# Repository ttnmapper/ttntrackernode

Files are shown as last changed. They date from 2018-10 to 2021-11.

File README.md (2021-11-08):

# TTN Tracker

The TTN Tracker is a [Things Network](https://www.thethingsnetwork.org/) node with a gps, used to map out coverage on [TTN Mapper](https://ttnmapper.org/). The device is aimed at end users, but can also be reprogrammed by more advanced users.

Thisrepository contains the schematics used to create the device as well as any additional files and the firmware that was loaded on the device.

### Schematics
The schematics were created using [KiCad 4.0.7](http://kicad.org/)

# Datasheets

These are links to the datasheets of important components used in the design.

 * [ATMEGA32U4](http://ww1.microchip.com/downloads/en/DeviceDoc/Atmel-7766-8-bit-AVR-ATmega16U4-32U4_Datasheet.pdf)  - Main Microcontroller
 * [RN2483](http://ww1.microchip.com/downloads/en/DeviceDoc/50002346C.pdf) - LoRa Module
 * [UBlox Cam M8Q](https://www.u-blox.com/sites/default/files/CAM-M8-FW3_DataSheet_%28UBX-15031574%29.pdf) - GPS
 	[Alternate datasheet](https://www.u-blox.com/sites/default/files/CAM-M8-FW3_HardwareIntegrationManual_%28UBX-15030063%29.pdf)
 * [MMA8452Q](https://www.nxp.com/docs/en/data-sheet/MMA8452Q.pdf) - Accelerometer
 * [MCP73831](http://ww1.microchip.com/downloads/en/DeviceDoc/20001984g.pdf) - LiPo Battery Charge management
 * [TLV71333PDBV](http://www.ti.com/lit/ds/symlink/tlv713p.pdf) - 3.3v Regulator

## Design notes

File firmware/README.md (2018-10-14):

# Firmware

All firmware was written in the Ardiuno IDE.

## Required Libraries

RN2xx3 Arduino Library from here:
https://github.com/jpmeijers/RN2483-Arduino-Library/

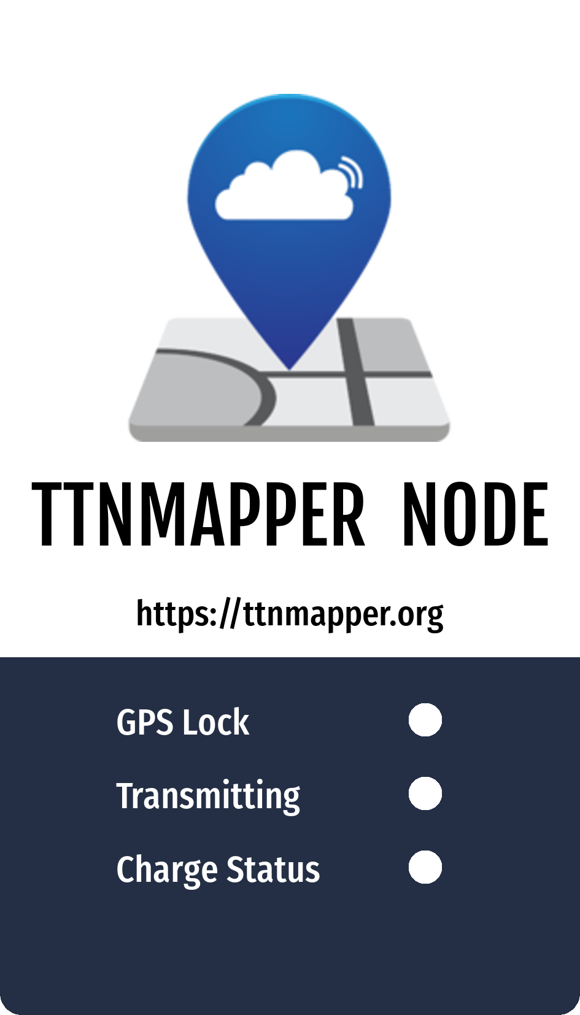
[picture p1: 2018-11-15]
enclosure/sticker design/tracker_sticker.png

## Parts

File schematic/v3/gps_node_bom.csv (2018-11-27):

Source: | C:\Users\Kolijn\Temp\ttntrackernode\schematic\v3\gps_node.sch
Date: | 2018/11/27 15:08:40
Tool: | Eeschema (5.0.1)-3
Generator: | C:\Program Files\KiCad\bin\scripting\plugins/bom_csv_grouped_by_value_with_fp.py
Component Count: | 86
Ref | Qnty | Value | Cmp name | Footprint | Description | Vendor |  | Digikey |  | RS
C4, C22, C29, C28, C20, C17, C7, C8, C9, C10, C11, C12, C23, C24, C13, C25, C27, | 17 | 100nF | C-Device | Capacitor_SMD:C_0805_2012Metric |  |  |  | 311-1361-1-ND | 0.16
C14, C15, | 2 | 22pF | C | Capacitor_SMD:C_0805_2012Metric | Unpolarized capacitor |  |  | 399-8036-1-ND | 0.14
C16, | 1 | 1uF | C-Device | Capacitor_SMD:C_0805_2012Metric |  |  |  | 399-1284-1-ND | 0.17
C18, C21, C30, C2, C6, C5, C3, C26, | 8 | 4.7uF | C-Device | Capacitor_SMD:C_0805_2012Metric
C19, C1, | 2 | NFM21HC105R1C3D | C_Feedthrough | gps_node_components:C_FEEDTHROUGH_0805 |  |  |  | 490-11839-1-ND | 0.47
C31, | 1 | C_Feedthrough | C_Feedthrough | gps_node_components:C_FEEDTHROUGH_0805 | Feedthrough capacitor |  |  | 490-11839-1-ND | 0.47
D1, D5, D6, | 3 | BAS K73 | D_Small | Diode_SMD:D_SOT-23_ANK |  |  |  |  |  | 738-4822 | 0.56
D2, | 1 | LED_Dual_CCAA | LED_Dual_CCAA-led_dual_ccaa | dual_led:LED_DUAL_1206 |  |  |  | 492-1245-1-ND | 0.68
D4, D3, | 2 | LED | LED-Device | LED_SMD:LED_0805_2012Metric_Pad1.15x1.40mm_HandSolder |  |  |  | 475-1278-1-ND | 0.38
 |  |  |  |  |  |  |  | 475-1410-1-ND | 0.36
F1, | 1 | Polyfuse | Polyfuse | gps_node_components:bourns polyfuse |  |  |  |  |  | 647-8184 | 6.833
IC1, | 1 | MCP73831/2 | MCP73831_2 | Package_TO_SOT_SMD:SOT-23-5 |  |  |  | MCP73831T-2ACI/OTCT-ND | 0.58
J1, J2, J3, J4, | 4 | Mounting Hole | Conn_01x01 | MountingHole:MountingHole_3.2mm_M3_ISO14580_Pad |  |  | DNP
J5, | 1 | TEST Vbatt | Conn_01x01 | Connector_PinHeader_2.54mm:PinHeader_1x01_P2.54mm_Vertical |  |  | DNP
J6, | 1 | USB_OTG | USB_OTG | gps_node_components:Molex_Microusb |  |  |  | WM1399CT-ND | 0.97
J7, | 1 | Test 3.3v | Conn_01x01 | Connector_PinHeader_2.54mm:PinHeader_1x01_P2.54mm_Vertical |  |  | DNP
J8, | 1 | Test Gnd | Conn_01x01 | Connector_PinHeader_2.54mm:PinHeader_1x01_P2.54mm_Vertical |  |  | DNP
J9, | 1 | Test V_bak | Conn_01x01 | Connector_PinHeader_2.54mm:PinHeader_1x01_P2.54mm_Vertical |  |  | DNP
J11, | 1 | AVR ICSP | Conn_02x03_Odd_Even | Connector_PinHeader_2.54mm:PinHeader_2x03_P2.54mm_Vertical |  |  | DNP
J12, | 1 | UART RF | Conn_01x03 | Connector_PinHeader_2.54mm:PinHeader_1x03_P2.54mm_Vertical |  |  | DNP
J13, | 1 | LIPO_BAT | Conn_01x02 | Connector_PinHeader_2.00mm:PinHeader_1x02_P2.00mm_Vertical |  |  |  | 455-1704-ND | 0.17
J15, | 1 | UART GPS | Conn_01x03 | Connector_PinHeader_2.54mm:PinHeader_1x03_P2.54mm_Vertical |  |  | DNP
J16, | 1 | FW_UPDATE | Conn_01x06 | Connector_PinHeader_2.54mm:PinHeader_1x06_P2.54mm_Vertical |  |  | DNP
J17, | 1 | u.FL connector | Conn_Coaxial | gps_node_components:CONN-RF-UFL |  |  |  |  |  | 557-981 | 10.932
R3, R2, | 2 | 220 | R-Device | Resistor_SMD:R_0805_2012Metric |  |  |  | 311-220ARCT-ND | 0.1
R4, R5, | 2 | 22 | R-Device | Resistor_SMD:R_0805_2012Metric |  |  |  | 311-22.0CRCT-ND | 0.1
R6, R11, R10, | 3 | 10k | R-Device | Resistor_SMD:R_0805_2012Metric |  |  |  | 311-10KARCT-ND | 0.1
R13, R12, | 2 | 1k | R-Device | Resistor_SMD:R_0805_2012Metric |  |  |  | 311-1.0KARCT-ND | 0.1
R14, | 1 | 2k | R_Small | Resistor_SMD:R_0805_2012Metric |  |  |  | 311-2.0KARCT-ND | 0.1
R16, R15, | 2 | 100k | R-Device | Resistor_SMD:R_0805_2012Metric |  |  |  | 311-100KCRCT-ND | 0.1
R18, R17, | 2 | 470 | R | Resistor_SMD:R_0805_2012Metric |  |  |  | 311-470ARCT-ND | 0.1
SW1, | 1 | Switch | SW_SPDT | EG1224:EG1224_Switch |  |  |  | EG2585-ND | 0.77
SW3, SW2, | 2 | SW_Push | SW_Push-Switch | Button_Switch_SMD:SW_SPST_PTS645 |  |  | DNP
TP3, TP4, TP7, TP5, TP6, TP8, TP2, TP1, | 8 | TestPoint | TestPoint-Connector | test_pad:test_pad |  |  | DNP
U1, U3, | 2 | TLV71333PDBV | TLV71333PDBV | Package_TO_SOT_SMD:SOT-23-5 |  |  |  | 296-35591-1-ND | 0.42
U2, | 1 | ublox-cam-m8q-0 | ublox-cam-m8q-0 | drawn_by_jpmeijers:ublox-cam-m8q-0 |  |  |  | 672-1013-1-ND | 35.15
U4, | 1 | ATMEGA32U4-AU | ATMEGA32U4-AU | Package_QFP:TQFP-44_10x10mm_P0.8mm |  |  |  | ATMEGA32U4-AU-ND | 4.12
U5, | 1 | RN2483 | RN2483 | drawn_by_jpmeijers:RN2483 |  |  |  | RN2483A-I/RM104-ND | 13.18
U6, | 1 | LIS3DH | LIS3DH-STM-LISxxx | Package_LGA:LGA-16_3x3mm_P0.5mm_LayoutBorder3x5y |  |  |  | 497-10613-1-ND | 0.79
Y1, | 1 | 16MHz | Crystal | gps_node_components:QC3CA_16MHz |  |  |  | 644-1178-1-ND | 1.03
 | 4 | Hex Standoffs M3 Nylon 5mm |  |  |  |  |  | RPC1483-ND | 0.65
 | 4 | Mach Screw Pan slotted M3x0.5 |  |  |  |  |  | 36-29341-ND | 0.2
 | 1 | Antenna |  | https://za.rs-online.com/web/p/telemetry-antennas/7934363/
 | 1 | SMA Cable & Antenna |  | https://www.robotics.org.za/UFL-SMA-868MHZ
 | 1 | Battery |  | https://www.robotics.org.za/503562?search=battery

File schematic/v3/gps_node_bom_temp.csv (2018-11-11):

Source: | /home/kolijn/Temp/ttntrackernode/schematic/v3/gps_node.sch
Date: | Sun 11 Nov 2018 14:27:34 SAST
Tool: | Eeschema 5.0.0-fee4fd1~66~ubuntu16.04.1
Generator: | /usr/share/kicad/plugins/bom_csv_grouped_by_value.py
Component Count: | 73
Individual Components:
Item | Qty | Reference(s) | Value | LibPart | Footprint
 |  | C1 | NFM21HC105R1C3D | gps_node-rescue:C_Feedthrough | gps_node_components:C_FEEDTHROUGH_0805
 |  | C2 | 10uF | gps_node-rescue:C | Capacitors_SMD:C_0805
 |  | C3 | 10uF | gps_node-rescue:C-Device | Capacitors_SMD:C_0805
 |  | C4 | 100nF | gps_node-rescue:C | Capacitors_SMD:C_0805
 |  | C5 | 10uF | gps_node-rescue:C-Device | Capacitors_SMD:C_0805
 |  | C6 | 10uF | gps_node-rescue:C-Device | Capacitors_SMD:C_0805
 |  | C7 | 100nF | gps_node-rescue:C-Device | Capacitors_SMD:C_0805
 |  | C8 | 100nF | gps_node-rescue:C-Device | Capacitors_SMD:C_0805
 |  | C9 | 100nF | gps_node-rescue:C-Device | Capacitors_SMD:C_0805
 |  | C10 | 100nF | gps_node-rescue:C-Device | Capacitors_SMD:C_0805
 |  | C11 | 100nF | gps_node-rescue:C-Device | Capacitors_SMD:C_0805
 |  | C12 | 100nF | gps_node-rescue:C-Device | Capacitors_SMD:C_0805
 |  | C13 | 100nF | gps_node-rescue:C-Device | Capacitors_SMD:C_0805
 |  | C14 | 22pF | gps_node-rescue:C-Device | Capacitors_SMD:C_0805
 |  | C15 | 22pF | gps_node-rescue:C-Device | Capacitors_SMD:C_0805
 |  | C16 | 1uF | gps_node-rescue:C-Device | Capacitors_SMD:C_0805
 |  | C17 | 100nF | gps_node-rescue:C-Device | Capacitors_SMD:C_0805
 |  | C18 | 10uF | gps_node-rescue:C_Small | Capacitors_SMD:C_0805
 |  | C19 | NFM21HC105R1C3D | gps_node-rescue:C_Feedthrough | gps_node_components:C_FEEDTHROUGH_0805
 |  | C20 | 100nF | gps_node-rescue:C-Device | Capacitors_SMD:C_0805
 |  | C21 | 100nF | gps_node-rescue:C_Small | Capacitors_SMD:C_0805
 |  | C22 | 100nF | gps_node-rescue:C | Capacitors_SMD:C_0805
 |  | C23 | 100nF | gps_node-rescue:C-Device | Capacitors_SMD:C_0805
 |  | C24 | 100nF | gps_node-rescue:C-Device | Capacitors_SMD:C_0805
 |  | C25 | 100nF | gps_node-rescue:C-Device | Capacitors_SMD:C_0805
 |  | C26 | 10uF | gps_node-rescue:C-Device | Capacitors_SMD:C_0805
 |  | C27 | 100nF | gps_node-rescue:C-Device | Capacitors_SMD:C_0805
 |  | D1 | BAS K73 | gps_node-rescue:D_Small | Diodes_SMD:D_SOT-23_ANK
 |  | D2 | LED_Dual_CCAA | gps_node-rescue:LED_Dual_CCAA-led_dual_ccaa | dual_led:LED_DUAL_1206
 |  | D3 | LED | gps_node-rescue:LED-Device | LEDs:LED_0805_HandSoldering
 |  | D4 | LED | gps_node-rescue:LED-Device | LEDs:LED_0805_HandSoldering
 |  | F1 | Polyfuse | gps_node-rescue:Polyfuse | gps_node_components:bourns polyfuse
 |  | IC1 | MCP73831/2 | gps_node-rescue:MCP73831_2 | TO_SOT_Packages_SMD:SOT-23-5
 |  | J1 | Mounting Hole | gps_node-rescue:Conn_01x01 | Mounting_Holes:MountingHole_3.2mm_M3_ISO14580_Pad
 |  | J2 | Mounting Hole | gps_node-rescue:Conn_01x01 | Mounting_Holes:MountingHole_3.2mm_M3_ISO14580_Pad
 |  | J3 | Mounting Hole | gps_node-rescue:Conn_01x01 | Mounting_Holes:MountingHole_3.2mm_M3_ISO14580_Pad
 |  | J4 | Mounting Hole | gps_node-rescue:Conn_01x01 | Mounting_Holes:MountingHole_3.2mm_M3_ISO14580_Pad
 |  | J5 | TEST Vbatt | gps_node-rescue:Conn_01x01 | Socket_Strips:Socket_Strip_Straight_1x01_Pitch2.54mm
 |  | J6 | USB_OTG | gps_node-rescue:USB_OTG | gps_node_components:Molex_Microusb
 |  | J7 | Test 3.3v | gps_node-rescue:Conn_01x01 | Socket_Strips:Socket_Strip_Straight_1x01_Pitch2.54mm
 |  | J8 | Test Gnd | gps_node-rescue:Conn_01x01 | Socket_Strips:Socket_Strip_Straight_1x01_Pitch2.54mm
 |  | J9 | Test V_bak | gps_node-rescue:Conn_01x01 | Socket_Strips:Socket_Strip_Straight_1x01_Pitch2.54mm
 |  | J11 | AVR ICSP | gps_node-rescue:Conn_02x03_Odd_Even | Pin_Headers:Pin_Header_Straight_2x03_Pitch2.54mm
 |  | J12 | UART RF | gps_node-rescue:Conn_01x03 | Pin_Headers:Pin_Header_Straight_1x03_Pitch2.54mm
 |  | J13 | LIPO_BAT | gps_node-rescue:Conn_01x02 | Connectors_Molex:Molex_PicoBlade_53047-0210_02x1.25mm_Straight
 |  | J15 | UART GPS | gps_node-rescue:Conn_01x03 | Pin_Headers:Pin_Header_Straight_1x03_Pitch2.54mm
 |  | J16 | FW_UPDATE | gps_node-rescue:Conn_01x06 | Pin_Headers:Pin_Header_Straight_1x06_Pitch2.54mm
 |  | J17 | u.FL connector | gps_node-rescue:Conn_Coaxial | gps_node_components:CONN-RF-UFL
 |  | R1 | 10k | gps_node-rescue:R_Small | Resistors_SMD:R_0805
 |  | R2 | 220 | gps_node-rescue:R-Device | Resistors_SMD:R_0805
 |  | R3 | 220 | gps_node-rescue:R-Device | Resistors_SMD:R_0805
 |  | R4 | 22 | gps_node-rescue:R-Device | Resistors_SMD:R_0805
 |  | R5 | 22 | gps_node-rescue:R-Device | Resistors_SMD:R_0805
 |  | R6 | 10k | gps_node-rescue:R-Device | Resistors_SMD:R_0805
 |  | R10 | 10k | gps_node-rescue:R-Device | Resistors_SMD:R_0805
 |  | R11 | 10k | gps_node-rescue:R-Device | Resistors_SMD:R_0805
 |  | R12 | 1k | gps_node-rescue:R-Device | Resistors_SMD:R_0805
 |  | R13 | 1k | gps_node-rescue:R-Device | Resistors_SMD:R_0805
 |  | R14 | 2k | gps_node-rescue:R_Small | Resistors_SMD:R_0805
 |  | R15 | 100k | gps_node-rescue:R-Device | Resistors_SMD:R_0805
 |  | R16 | 100k | gps_node-rescue:R-Device | Resistors_SMD:R_0805
 |  | R17 | 470 | gps_node-rescue:R | Resistors_SMD:R_0805
 |  | R18 | 470 | gps_node-rescue:R | Resistors_SMD:R_0805
 |  | SW1 | RS stock no. 448-0747 | gps_node-rescue:SW_SPDT | EG1224:EG1224_Switch
 |  | SW2 | SW_Push | gps_node-rescue:SW_Push-Switch | Buttons_Switches_SMD:SW_SPST_PTS645
 |  | SW3 | SW_Push | gps_node-rescue:SW_Push-Switch | Buttons_Switches_SMD:SW_SPST_PTS645
 |  | U1 | TLV71333PDBV | gps_node-rescue:TLV71333PDBV | TO_SOT_Packages_SMD:SOT-23-5
 |  | U2 | ublox-cam-m8q-0 | drawn_by_jpmeijers:ublox-cam-m8q-0 | drawn_by_jpmeijers:ublox-cam-m8q-0
 |  | U3 | TLV71333PDBV | gps_node-rescue:TLV71333PDBV | TO_SOT_Packages_SMD:SOT-23-5
 |  | U4 | ATMEGA32U4-AU | gps_node-rescue:ATMEGA32U4-AU | Housings_QFP:TQFP-44_10x10mm_Pitch0.8mm
 |  | U5 | RN2483 | drawn_by_jpmeijers:RN2483 | drawn_by_jpmeijers:RN2483
 |  | U6 | LIS3DH | gps_node-rescue:LIS3DH-STM-LISxxx | lga_16:LGA16-pitch0.5-3mmx3mm
 |  | Y1 | 16MHz | gps_node-rescue:Crystal | gps_node_components:QC3CA_16MHz
 |  |  |  |  |  |  |  | Exchange: | 14.37
Collated Components:
Item | Qty | Reference(s) | Value | LibPart | Footprint | Description | Digikey | Dollar | RS | Rand
1 | 2 | C1, C19 | NFM21HC105R1C3D | gps_node-rescue:C_Feedthrough | gps_node_components:C_FEEDTHROUGH_0805 |  | 490-11839-1-ND | 0.47 |  |  | R 13.51
2 | 1 | C2 | 10uF | gps_node-rescue:C | Capacitors_SMD:C_0805 |  | 1276-2399-1-ND | 0.25 |  |  | R 3.59
3 | 4 | C3, C5, C6, C26 | 10uF | gps_node-rescue:C-Device | Capacitors_SMD:C_0805 |  | 1276-2399-1-ND | 0.25 |  |  | R 14.37
4 | 2 | C4, C22 | 100nF | gps_node-rescue:C | Capacitors_SMD:C_0805 |  | 311-1361-1-ND | 0.16 |  |  | R 4.60
5 | 13 | C7, C8, C9, C10, C11, C12, C13, C17, C20, C23, C24, C25, C27 | 100nF | gps_node-rescue:C-Device | Capacitors_SMD:C_0805 |  | 311-1361-1-ND | 0.16 |  |  | R 29.89
6 | 2 | C14, C15 | 22pF | gps_node-rescue:C-Device | Capacitors_SMD:C_0805 |  | 399-8036-1-ND | 0.14 |  |  | R 4.02
7 | 1 | C16 | 1uF | gps_node-rescue:C-Device | Capacitors_SMD:C_0805 |  | 399-1284-1-ND | 0.17 |  |  | R 2.44
8 | 1 | C18 | 10uF | gps_node-rescue:C_Small | Capacitors_SMD:C_0805 |  | 1276-2399-1-ND | 0.25 |  |  | R 3.59
9 | 1 | C21 | 100nF | gps_node-rescue:C_Small | Capacitors_SMD:C_0805 |  | 311-1361-1-ND | 0.16 |  |  | R 2.30
10 | 1 | D1 | BAS K73 | gps_node-rescue:D_Small | Diodes_SMD:D_SOT-23_ANK |  |  |  | 738-4822 | 0.56 | R 0.56
11 | 1 | D2 | LED_Dual_CCAA | gps_node-rescue:LED_Dual_CCAA-led_dual_ccaa | dual_led:LED_DUAL_1206 |  | 492-1245-1-ND | 0.68 |  |  | R 9.77
12 | 2 | D3 | LED | gps_node-rescue:LED-Device | LEDs:LED_0805_HandSoldering |  | 475-1278-1-ND | 0.38 |  |  | R 10.92
 |  | D4 | LED | gps_node-rescue:LED-Device | LEDs:LED_0805_HandSoldering |  | 475-1410-1-ND | 0.36 |  |  | R 0.00
13 | 1 | F1 | Polyfuse | gps_node-rescue:Polyfuse | gps_node_components:bourns polyfuse |  |  |  | 647-8184 | 6.833 | R 6.83
14 | 1 | IC1 | MCP73831/2 | gps_node-rescue:MCP73831_2 | TO_SOT_Packages_SMD:SOT-23-5 |  | MCP73831T-2ACI/OTCT-ND | 0.58 |  |  | R 8.33
15 | 4 | J1, J2, J3, J4 | Mounting Hole | gps_node-rescue:Conn_01x01 | Mounting_Holes:MountingHole_3.2mm_M3_ISO14580_Pad | NO Populate |  |  |  |  | R 0.00
16 | 1 | J5 | TEST Vbatt | gps_node-rescue:Conn_01x01 | Socket_Strips:Socket_Strip_Straight_1x01_Pitch2.54mm | NO Populate |  |  |  |  | R 0.00
17 | 1 | J6 | USB_OTG | gps_node-rescue:USB_OTG | gps_node_components:Molex_Microusb |  | WM1399CT-ND | 0.97 |  |  | R 13.94
18 | 1 | J7 | Test 3.3v | gps_node-rescue:Conn_01x01 | Socket_Strips:Socket_Strip_Straight_1x01_Pitch2.54mm | NO Populate |  |  |  |  | R 0.00
19 | 1 | J8 | Test Gnd | gps_node-rescue:Conn_01x01 | Socket_Strips:Socket_Strip_Straight_1x01_Pitch2.54mm | NO Populate |  |  |  |  | R 0.00
20 | 1 | J9 | Test V_bak | gps_node-rescue:Conn_01x01 | Socket_Strips:Socket_Strip_Straight_1x01_Pitch2.54mm | NO Populate |  |  |  |  | R 0.00
21 | 1 | J11 | AVR ICSP | gps_node-rescue:Conn_02x03_Odd_Even | Pin_Headers:Pin_Header_Straight_2x03_Pitch2.54mm | NO Populate |  |  |  |  | R 0.00
22 | 1 | J12 | UART RF | gps_node-rescue:Conn_01x03 | Pin_Headers:Pin_Header_Straight_1x03_Pitch2.54mm | NO Populate |  |  |  |  | R 0.00
23 | 1 | J13 | LIPO_BAT | gps_node-rescue:Conn_01x02 | Connectors_Molex:Molex_PicoBlade_53047-0210_02x1.25mm_Straight |  | 455-1704-ND | 0.17 |  |  | R 2.44
24 | 1 | J15 | UART GPS | gps_node-rescue:Conn_01x03 | Pin_Headers:Pin_Header_Straight_1x03_Pitch2.54mm | NO Populate |  |  |  |  | R 0.00
25 | 1 | J16 | FW_UPDATE | gps_node-rescue:Conn_01x06 | Pin_Headers:Pin_Header_Straight_1x06_Pitch2.54mm | NO Populate |  |  |  |  | R 0.00
26 | 1 | J17 | u.FL connector | gps_node-rescue:Conn_Coaxial | gps_node_components:CONN-RF-UFL |  |  |  | 557-981 | 10.932 | R 10.93
27 | 1 | R1 | 10k | gps_node-rescue:R_Small | Resistors_SMD:R_0805 |  | 311-10KARCT-ND | 0.1 |  |  | R 1.44
28 | 2 | R2, R3 | 220 | gps_node-rescue:R-Device | Resistors_SMD:R_0805 |  | 311-220ARCT-ND | 0.1 |  |  | R 2.87
29 | 2 | R4, R5 | 22 | gps_node-rescue:R-Device | Resistors_SMD:R_0805 |  | 311-22.0CRCT-ND | 0.1 |  |  | R 2.87
30 | 3 | R6, R10, R11 | 10k | gps_node-rescue:R-Device | Resistors_SMD:R_0805 |  | 311-10KARCT-ND | 0.1 |  |  | R 4.31
31 | 2 | R12, R13 | 1k | gps_node-rescue:R-Device | Resistors_SMD:R_0805 |  | 311-1.0KARCT-ND | 0.1 |  |  | R 2.87
32 | 1 | R14 | 2k | gps_node-rescue:R_Small | Resistors_SMD:R_0805 |  | 311-2.0KARCT-ND | 0.1 |  |  | R 1.44
33 | 2 | R15, R16 | 100k | gps_node-rescue:R-Device | Resistors_SMD:R_0805 |  | 311-100KCRCT-ND | 0.1 |  |  | R 2.87
34 | 2 | R17, R18 | 470 | gps_node-rescue:R | Resistors_SMD:R_0805 |  | 311-470ARCT-ND | 0.1 |  |  | R 2.87
35 | 1 | SW1 | RS stock no. 448-0747 | gps_node-rescue:SW_SPDT | EG1224:EG1224_Switch |  | EG2585-ND | 0.77 |  |  | R 11.06
36 | 2 | SW2, SW3 | SW_Push | gps_node-rescue:SW_Push-Switch | Buttons_Switches_SMD:SW_SPST_PTS645 | NO Populate |  |  |  |  | R 0.00
37 | 2 | U1, U3 | TLV71333PDBV | gps_node-rescue:TLV71333PDBV | TO_SOT_Packages_SMD:SOT-23-5 |  | 296-35591-1-ND | 0.42 |  |  | R 12.07
38 | 1 | U2 | ublox-cam-m8q-0 | drawn_by_jpmeijers:ublox-cam-m8q-0 | drawn_by_jpmeijers:ublox-cam-m8q-0 |  | 672-1013-1-ND | 35.15 |  |  | R 505.11
39 | 1 | U4 | ATMEGA32U4-AU | gps_node-rescue:ATMEGA32U4-AU | Housings_QFP:TQFP-44_10x10mm_Pitch0.8mm |  | ATMEGA32U4-AU-ND | 4.12 |  |  | R 59.20
40 | 1 | U5 | RN2483 | drawn_by_jpmeijers:RN2483 | drawn_by_jpmeijers:RN2483 |  | RN2483A-I/RM104-ND | 13.18 |  |  | R 189.40
41 | 1 | U6 | LIS3DH | gps_node-rescue:LIS3DH-STM-LISxxx | lga_16:LGA16-pitch0.5-3mmx3mm |  | 497-10613-1-ND | 0.79 |  |  | R 11.35
42 | 1 | Y1 | 16MHz | gps_node-rescue:Crystal | gps_node_components:QC3CA_16MHz | 8MHz | 644-1178-1-ND | 1.03 |  |  | R 14.80
 |  |  |  |  |  |  |  |  |  |  | R 0.00
43 | 4 | Hex Standoffs M3 Nylon 5mm |  |  |  |  | RPC1483-ND | 0.65 |  |  | R 37.36
44 | 4 | Mach Screw Pan slotted M3x0.5 |  |  |  |  | 36-29341-ND | 0.2 |  |  | R 11.50
45 | 1 | Antenna |  | https://za.rs-online.com/web/p/telemetry-antennas/7934363/ |  |  |  |  |  | 98.18 | R 98.18
46 | 1 | SMA Cable & Antenna |  | https://www.robotics.org.za/UFL-SMA-868MHZ |  |  |  |  |  | 60 | R 60.00
47 | 1 | Battery |  | https://www.robotics.org.za/503562?search=battery |  |  |  |  |  | 165 | R 165.00
 |  |  |  |  |  |  |  |  |  |  | R 1,338.64

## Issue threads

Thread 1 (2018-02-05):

schematic as PDF

urs8000, 2018-02-05:
hi
not all are using KiCad,so it would be very friendly if you could add a PDF printout of the schematic and the board.

additionally I suggest using an atmega1284p with more memory and hardware serial.
I added an OpenLog board for logging each send, to disguinguish between received and lost packages (red / green dotted map)
https://github.com/urs8000/LoRa-Gateway-Locator

jpmeijers, 2018-02-05:
The design is still a work in progress, so creating a PDF of the schematic now is a bit premature.

Using a more expensive ATmega1284p is overkill as we make use of the RN2483 and therefore do not need the extra memory (as we don't use the LMIC stack). The 32u4 has native USB, giving you a "hardware" serial to the computer. That leaves the hardware serial port open for use with the RN2483.

Another reason for using the ATmega32u4 is compatibility with the Things Uno and Things Node. This way you can use The Things Network libraries on this device without any changes.

TD-er, 2019-07-01:
Well, it doesn't look like there has been a lot of recent activity on the PCB, so I would not mind having a schematic in either PNG or PDF.
Now I have to install KiCad to look at the schematics.

Closed 2018-02-05.

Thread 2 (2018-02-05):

RN2483 Reset Pin

dbrgn, 2018-02-05:
I've heard someone complain that the RN2483 can get stuck. Not sure if that's true, but it might be good to connect the reset pin to the microcontroller, just in case :)

jpmeijers, 2018-02-05:
Really good point. The reset pin should indeed be connected.

KolijnWolfaardt, 2018-02-05:
Thank you @dbrgn, I'll change that

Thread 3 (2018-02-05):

LEDs

dbrgn, 2018-02-05:
I'm not sure if I missed it in the schematics, but some more status LEDs would be useful:

- LoRaWAN join state (for OTAA)
- When data is sent over LoRaWAN (could be combined with join state)
- GPS fix (an RGB LED or just a yellow and a green LED to indicate accuracy would be awesome)

KolijnWolfaardt, 2018-02-05:
Hi @dbrgn, thanks for the suggestion, it will definitely help make the software state of the tracker more visible. Do you know of a specific LED you'd like to suggest, and would you like to implement it?

dbrgn, 2018-02-06:
No, I was thinking of generic 0805 SMD LEDs, unless you want to use a WS2812b RGB LED aka Neopixel. But labelled single LEDs are easier to understand than memorizing color codes :)

> would you like to implement it

Not this week, but maybe later (unless you want to do it yourself). Where do you usually get your parts, Digikey? (I think it's important that all parts in KiCad have an order number in the metadata.)

KolijnWolfaardt, 2018-04-11:
Commit 4d2b95 adds an WS2812b led.

Closed 2018-04-11.

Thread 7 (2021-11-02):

Clarifications needed

catalinalb, 2021-11-02:
Hello,

Would like to flash my TTGO T-beam (with OLED) with TTN Tracker.
Unfortunatly I don´t really understand for what boards it can be used.
Can someone add some clairfications or help me out?

Thank you

jpmeijers, 2021-11-03:
Have a look at https://github.com/ttnmapper/gps-node-examples to find example for different devices.

This repo is a specific device and won't work on different hardware.

Closed 2021-11-03.

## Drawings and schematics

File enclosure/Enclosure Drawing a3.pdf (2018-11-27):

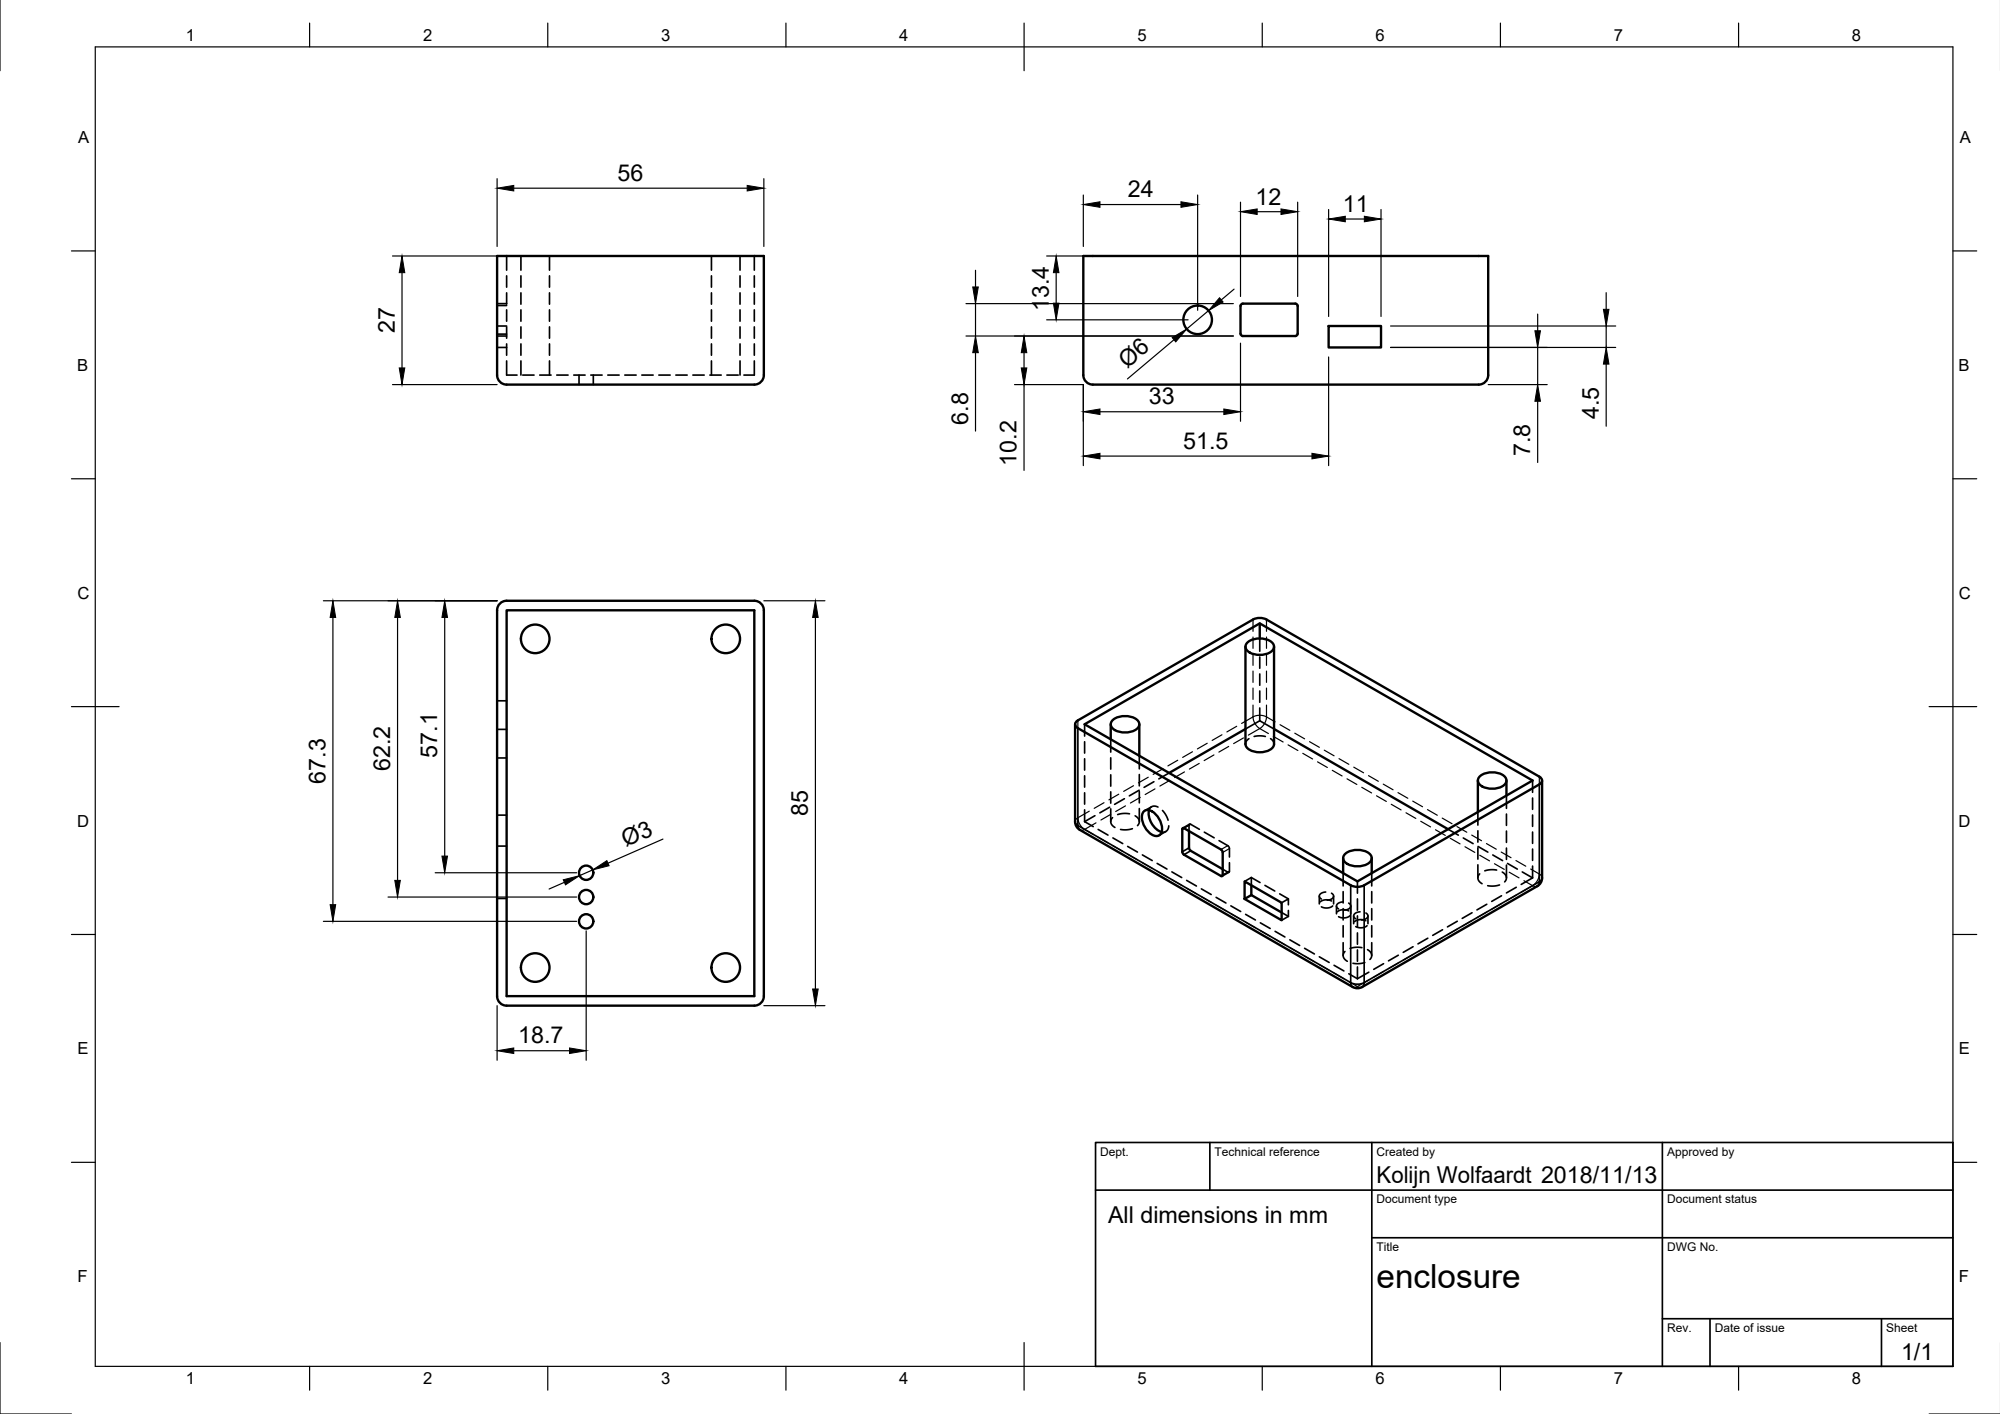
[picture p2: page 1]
Kolijn Wolfaardt7.8

All dimensions in mm 85

Dept. | Technical reference | Created by 2018/11/13 | Approved by

Document type | Document status

Title enclosure | DWG No.

Rev. | Date of issue | Sheet 1/1

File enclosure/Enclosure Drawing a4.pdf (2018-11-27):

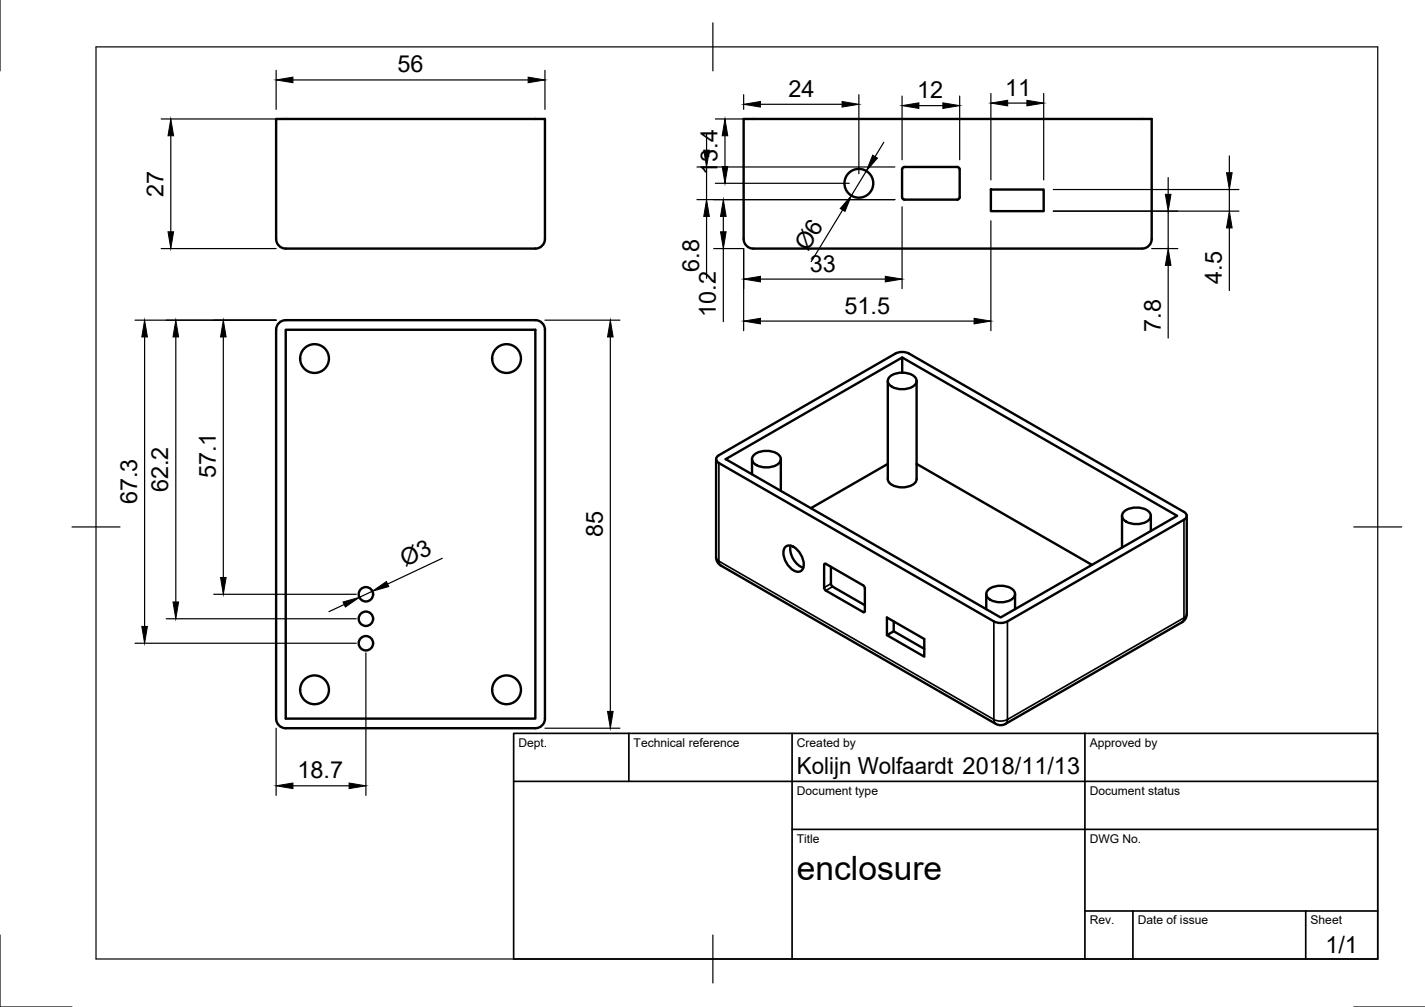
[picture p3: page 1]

Dept. | Technical reference | Created by Kolijn Wolfaardt 2018/11/13 | Approved by

Document type | Document status

Title enclosure | DWG No.

Rev. | Date of issue | Sheet 1/1

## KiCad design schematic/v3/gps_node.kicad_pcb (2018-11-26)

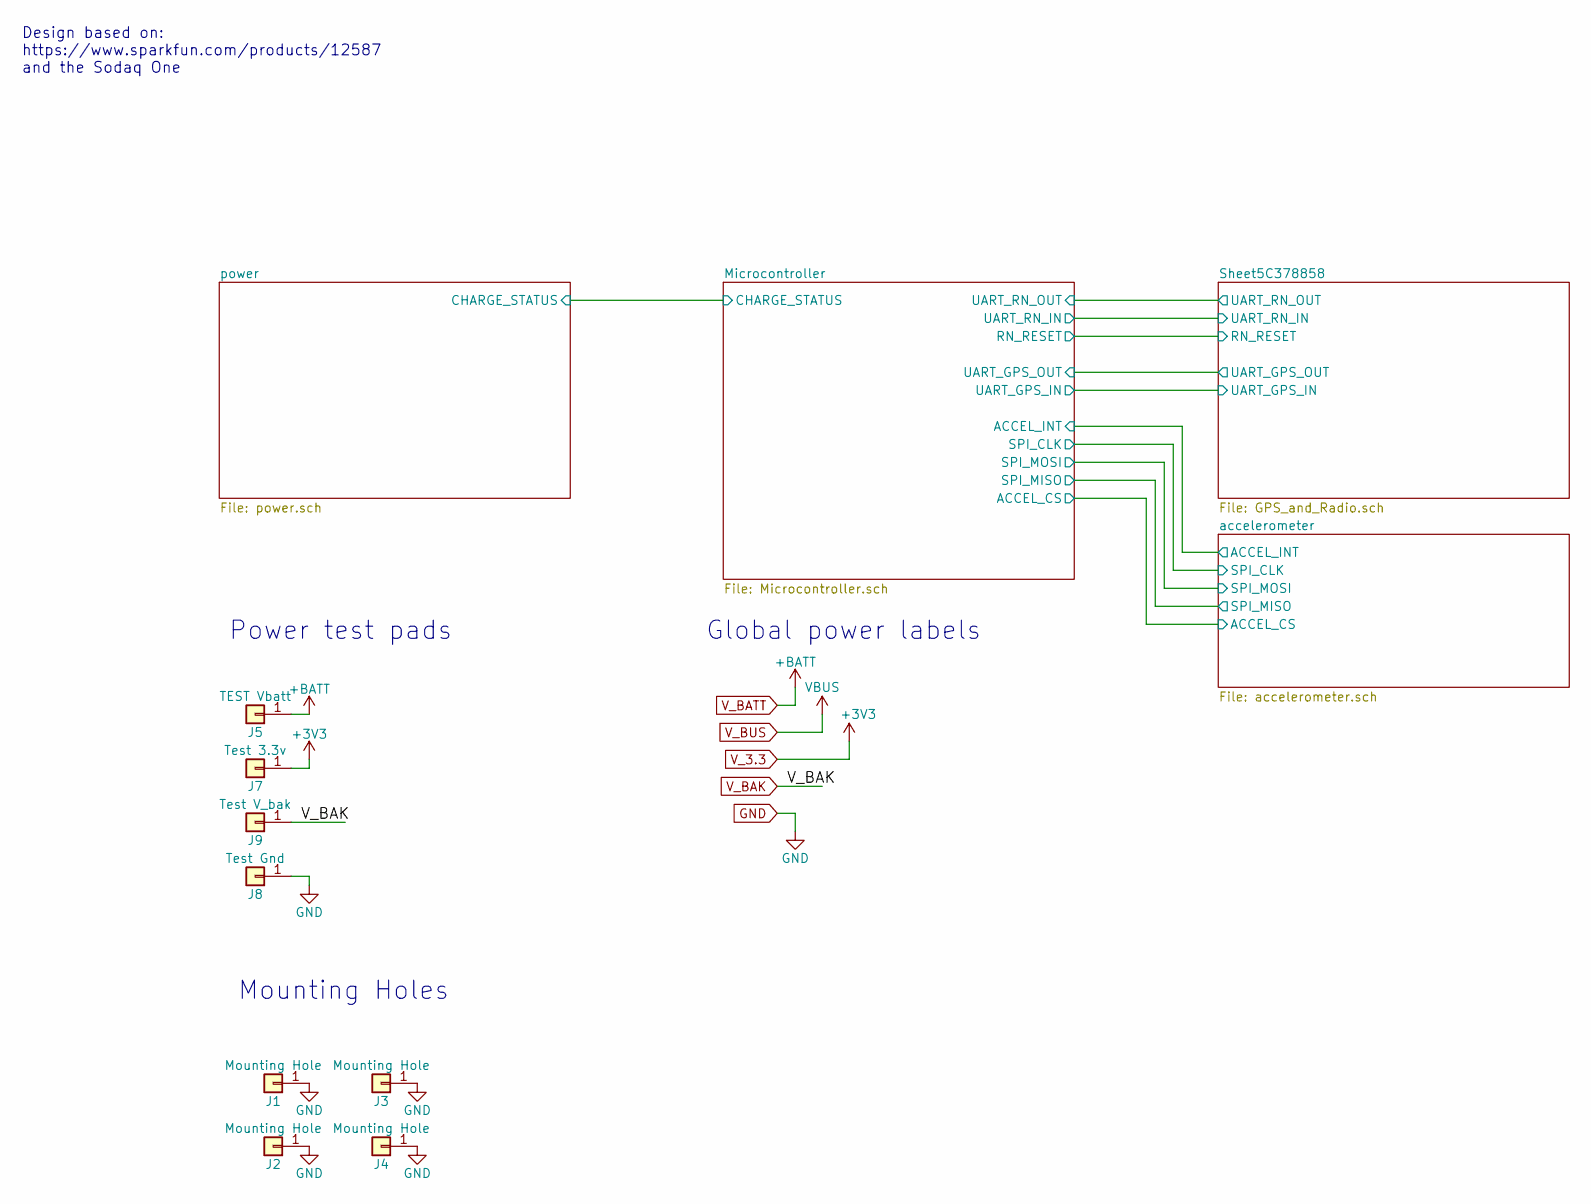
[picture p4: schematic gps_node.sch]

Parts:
J1, J2, J3, J4: Mounting Hole; MountingHole_3.2mm_M3_ISO14580_Pad
J5: TEST Vbatt; PinHeader_1x01_P2.54mm_Vertical
J7: Test 3.3v; PinHeader_1x01_P2.54mm_Vertical
J8: Test Gnd; PinHeader_1x01_P2.54mm_Vertical
J9: Test V_bak; PinHeader_1x01_P2.54mm_Vertical

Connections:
GND: J1.1, J2.1, J3.1, J4.1, J8.1; also elsewhere on the board
V_3.3: J7.1; also elsewhere on the board
V_BAK: J9.1; also elsewhere on the board
V_BATT: J5.1; also elsewhere on the board

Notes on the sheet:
Design based on: https://www.sparkfun.com/products/12587 and the Sodaq One
Global power labels
Power test pads
Mounting Holes

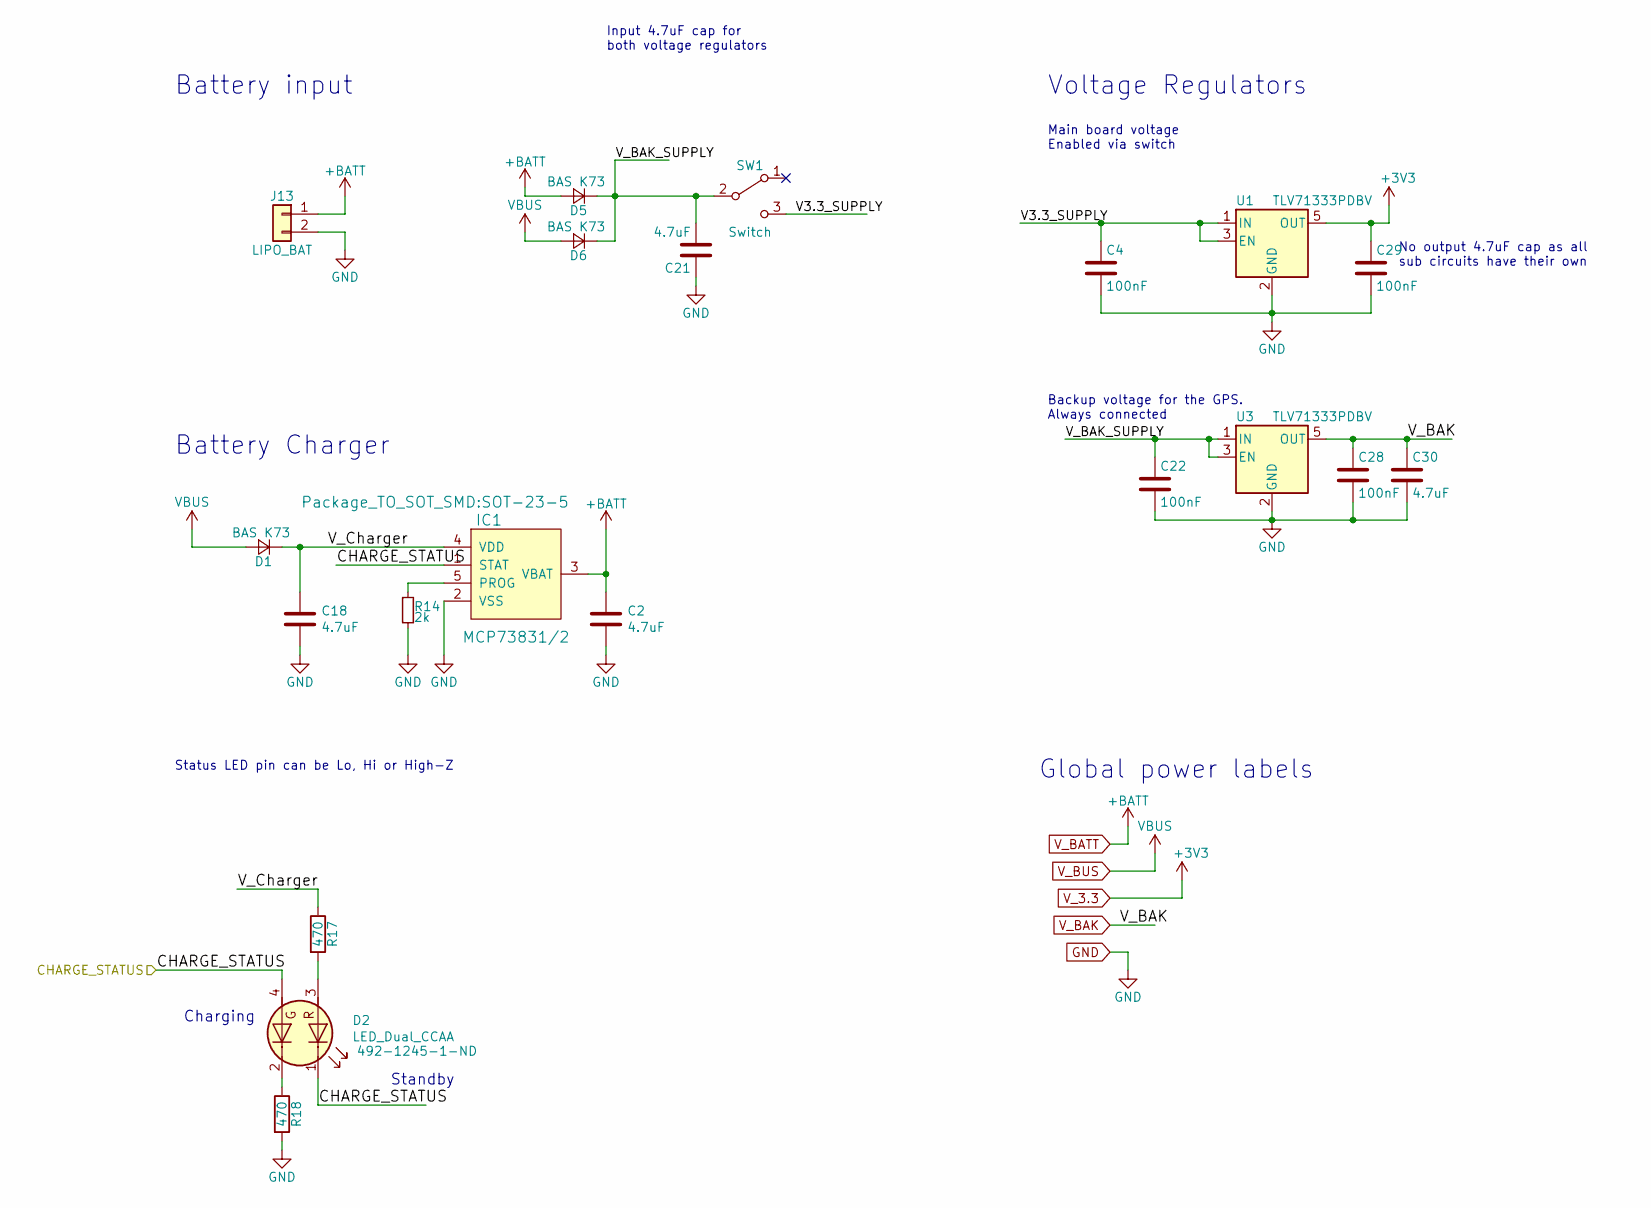
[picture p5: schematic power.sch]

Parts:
C2, C18, C21, C30: 4.7uF; C_0805_2012Metric
C4, C22, C28, C29: 100nF; C_0805_2012Metric
D1, D5, D6: BAS K73; D_SOT-23_ANK
D2: LED_Dual_CCAA; LED_DUAL_1206; Digikey 492-1245-1-ND
IC1: MCP73831/2; SOT-23-5
J13: LIPO_BAT; PinHeader_1x02_P2.00mm_Vertical
R14: 2k; R_0805_2012Metric
R17, R18: 470; R_0805_2012Metric
SW1: Switch; EG1224_Switch
U1, U3: TLV71333PDBV; SOT-23-5

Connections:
/Microcontroller/CHARGE_STATUS: D2.1 (A1), D2.4 (K2), IC1.1 (STAT); also elsewhere on the board
/power/V3.3_SUPPLY: C4.1, SW1.3 (C), U1.1 (IN), U1.3 (EN)
/power/V_BAK_SUPPLY: C21.2, C22.1, D5.1 (K), D6.1 (K), SW1.2 (B), U3.1 (IN), U3.3 (EN)
/power/V_Charger: C18.1, D1.1 (K), IC1.4 (VDD), R17.1
GND: C2.2, C4.2, C18.2, C21.1, C22.2, C28.2, C29.2, C30.2, IC1.2 (VSS), J13.2, R14.2, R18.2, U1.2 (GND), U3.2 (GND); also elsewhere on the board
unnamed: D2.2 (A2), R18.1
unnamed: D2.3 (K1), R17.2
unnamed: IC1.5 (PROG), R14.1
V_3.3: C29.1, U1.5 (OUT); also elsewhere on the board
V_BAK: C28.1, C30.1, U3.5 (OUT); also elsewhere on the board
V_BATT: C2.1, D5.2 (A), IC1.3 (VBAT), J13.1; also elsewhere on the board
V_BUS: D1.2 (A), D6.2 (A); also elsewhere on the board

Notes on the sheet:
Charging
Standby
Voltage Regulators
Backup voltage for the GPS. Always connected
Main board voltage Enabled via switch
Battery Charger
Status LED pin can be Lo, Hi or High-Z
Battery input
Global power labels
Input 4.7uF cap for both voltage regulators
No output 4.7uF cap as all sub circuits have their own

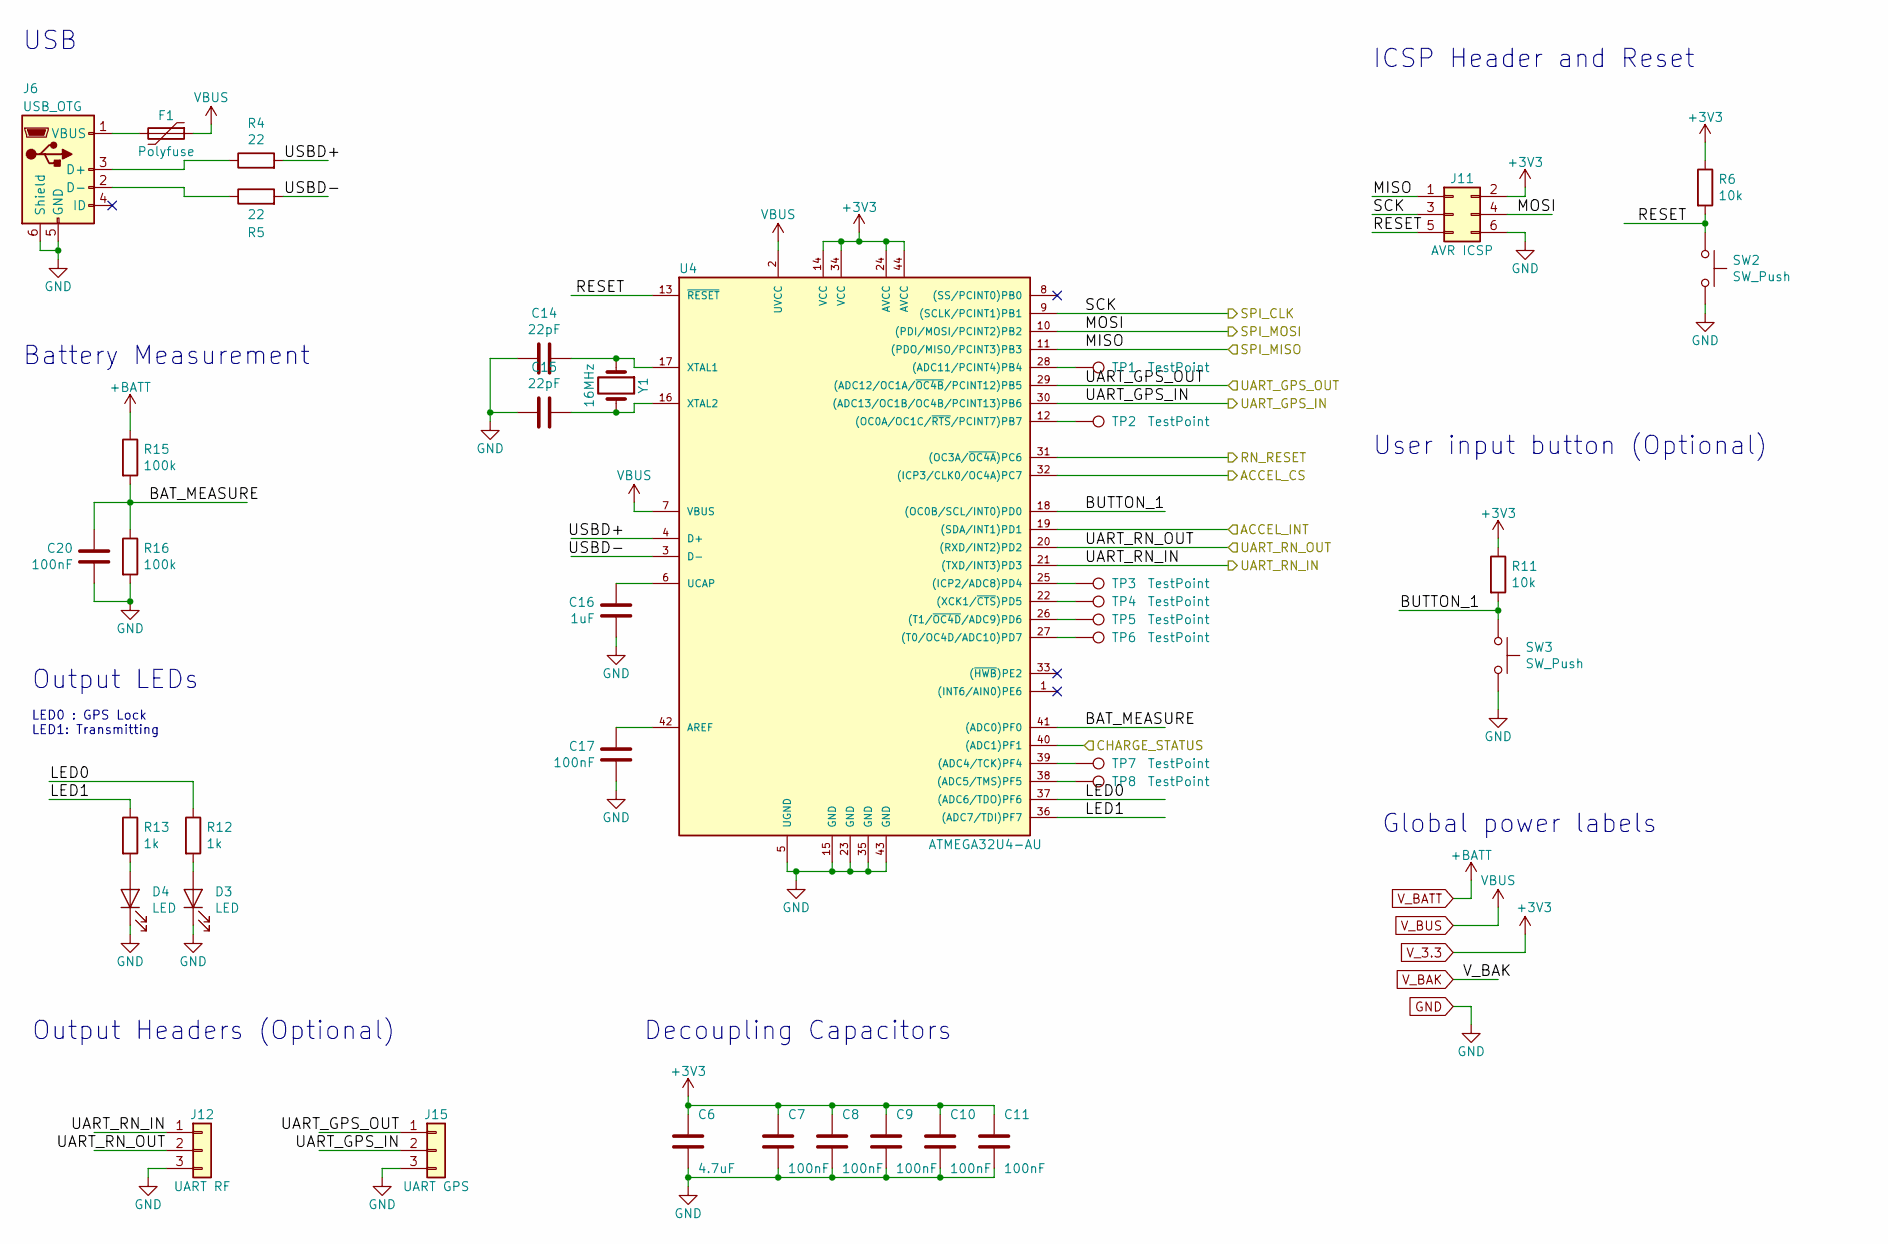
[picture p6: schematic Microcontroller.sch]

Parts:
C6: 4.7uF; C_0805_2012Metric
C7, C8, C9, C10, C11, C17, C20: 100nF; C_0805_2012Metric
C14, C15: 22pF; C_0805_2012Metric
C16: 1uF; C_0805_2012Metric
D3, D4: LED; LED_0805_2012Metric_Pad1.15x1.40mm_HandSolder
F1: Polyfuse; bourns polyfuse
J6: USB_OTG; Molex_Microusb
J11: AVR ICSP; PinHeader_2x03_P2.54mm_Vertical
J12: UART RF; PinHeader_1x03_P2.54mm_Vertical
J15: UART GPS; PinHeader_1x03_P2.54mm_Vertical
R4, R5: 22; R_0805_2012Metric
R6, R11: 10k; R_0805_2012Metric
R12, R13: 1k; R_0805_2012Metric
R15, R16: 100k; R_0805_2012Metric
SW2, SW3: SW_Push; SW_SPST_PTS645
TP1, TP2, TP3, TP4, TP5, TP6, TP7, TP8: TestPoint; test_pad
U4: ATMEGA32U4-AU; TQFP-44_10x10mm_P0.8mm
Y1: 16MHz; QC3CA_16MHz

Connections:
/Microcontroller/ACCEL_CS: U4.32 ((ICP3/CLK0/OC4A)PC7); also elsewhere on the board
/Microcontroller/ACCEL_INT: U4.19 ((SDA/INT1)PD1); also elsewhere on the board
/Microcontroller/BAT_MEASURE: C20.2, R15.2, R16.1, U4.41 ((ADC0)PF0)
/Microcontroller/BUTTON_1: R11.2, SW3.1, U4.18 ((OC0B/SCL/INT0)PD0)
/Microcontroller/CHARGE_STATUS: U4.40 ((ADC1)PF1); also elsewhere on the board
/Microcontroller/LED0: R12.1, U4.37 ((ADC6/TDO)PF6)
/Microcontroller/LED1: R13.1, U4.36 ((ADC7/TDI)PF7)
/Microcontroller/RESET: J11.5, R6.2, SW2.1, U4.13 (~RESET~)
/Microcontroller/RN_RESET: U4.31 ((OC3A/~OC4A~)PC6); also elsewhere on the board
/Microcontroller/SPI_CLK: J11.3, U4.9 ((SCLK/PCINT1)PB1); also elsewhere on the board
/Microcontroller/SPI_MISO: J11.1, U4.11 ((PDO/MISO/PCINT3)PB3); also elsewhere on the board
/Microcontroller/SPI_MOSI: J11.4, U4.10 ((PDI/MOSI/PCINT2)PB2); also elsewhere on the board
/Microcontroller/UART_GPS_IN: J15.2, U4.30 ((ADC13/OC1B/OC4B/PCINT13)PB6); also elsewhere on the board
/Microcontroller/UART_GPS_OUT: J15.1, U4.29 ((ADC12/OC1A/~OC4B~/PCINT12)PB5); also elsewhere on the board
/Microcontroller/UART_RN_IN: J12.1, U4.21 ((TXD/INT3)PD3); also elsewhere on the board
/Microcontroller/UART_RN_OUT: J12.2, U4.20 ((RXD/INT2)PD2); also elsewhere on the board
/Microcontroller/USBD+: R4.2, U4.4 (D+)
/Microcontroller/USBD-: R5.2, U4.3 (D-)
GND: C6.2, C7.2, C8.2, C9.2, C10.2, C11.2, C14.2, C15.2, C16.1, C17.1, C20.1, D3.1 (K), D4.1 (K), J6.5 (GND), J6.6 (Shield), J11.6, J12.3, J15.3, R16.2, SW2.2, SW3.2, U4.5 (UGND), U4.15 (GND), U4.23 (GND), U4.35 (GND), U4.43 (GND); also elsewhere on the board
unnamed: C14.1, U4.17 (XTAL1), Y1.1
unnamed: C15.1, U4.16 (XTAL2), Y1.2
unnamed: C16.2, U4.6 (UCAP)
unnamed: C17.2, U4.42 (AREF)
unnamed: D3.2 (A), R12.2
unnamed: D4.2 (A), R13.2
unnamed: F1.2, J6.1 (VBUS)
unnamed: J6.2 (D-), R5.1
unnamed: J6.3 (D+), R4.1
unnamed: TP1.1, U4.28 ((ADC11/PCINT4)PB4)
unnamed: TP2.1, U4.12 ((OC0A/OC1C/~RTS~/PCINT7)PB7)
unnamed: TP3.1, U4.25 ((ICP2/ADC8)PD4)
unnamed: TP4.1, U4.22 ((XCK1/~CTS~)PD5)
unnamed: TP5.1, U4.26 ((T1/~OC4D~/ADC9)PD6)
unnamed: TP6.1, U4.27 ((T0/OC4D/ADC10)PD7)
unnamed: TP7.1, U4.39 ((ADC4/TCK)PF4)
unnamed: TP8.1, U4.38 ((ADC5/TMS)PF5)
V_3.3: C6.1, C7.1, C8.1, C9.1, C10.1, C11.1, J11.2, R6.1, R11.1, U4.14 (VCC), U4.24 (AVCC), U4.34 (VCC), U4.44 (AVCC); also elsewhere on the board
V_BATT: R15.1; also elsewhere on the board
V_BUS: F1.1, U4.2 (UVCC), U4.7 (VBUS); also elsewhere on the board

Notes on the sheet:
Global power labels
USB
Battery Measurement
Output LEDs
LED0 : GPS Lock LED1: Transmitting
Output Headers (Optional)
ICSP Header and Reset
User input button (Optional)
Decoupling Capacitors

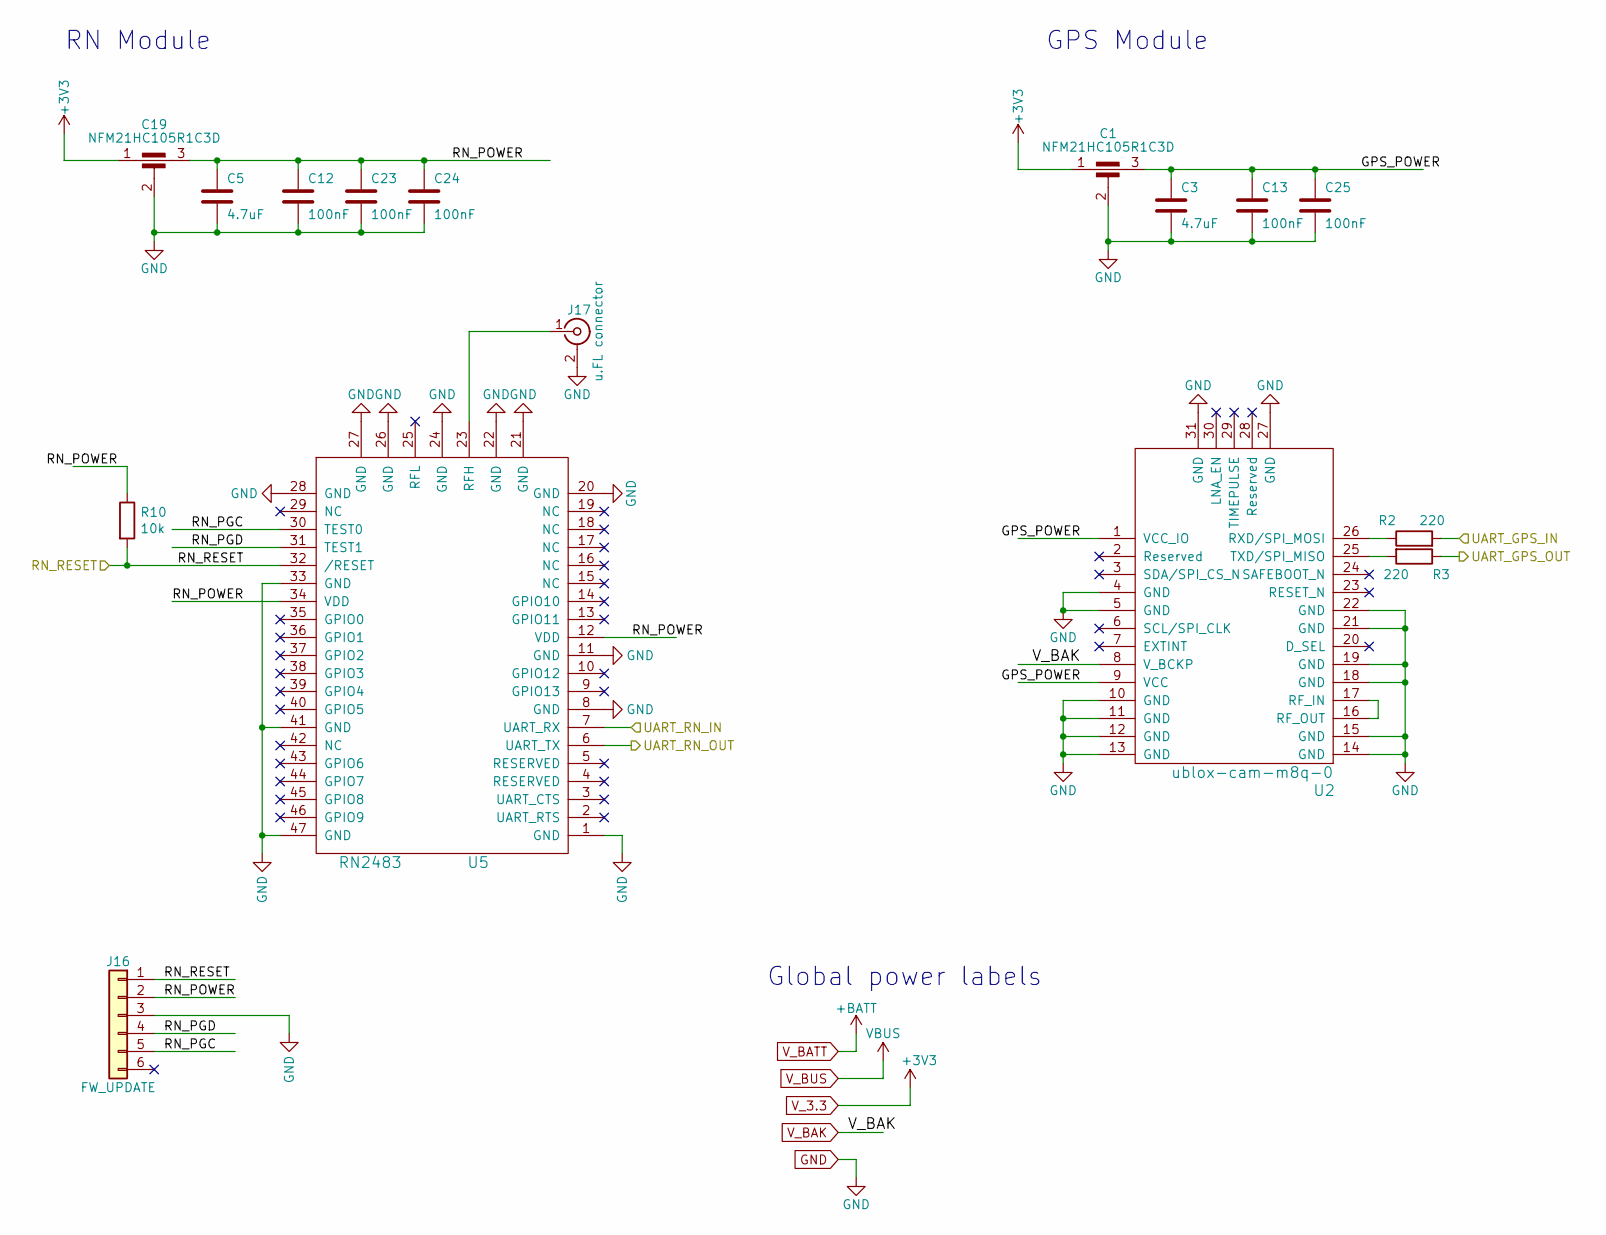
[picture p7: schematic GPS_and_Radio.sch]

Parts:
C1, C19: NFM21HC105R1C3D; C_FEEDTHROUGH_0805
C3, C5: 4.7uF; C_0805_2012Metric
C12, C13, C23, C24, C25: 100nF; C_0805_2012Metric
J16: FW_UPDATE; PinHeader_1x06_P2.54mm_Vertical
J17: u.FL connector; CONN-RF-UFL
R2, R3: 220; R_0805_2012Metric
R10: 10k; R_0805_2012Metric
U2: ublox-cam-m8q-0
U5: RN2483

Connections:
/Microcontroller/RN_RESET: J16.1, R10.2, U5.32 (/RESET); also elsewhere on the board
/Microcontroller/UART_GPS_IN: R2.2; also elsewhere on the board
/Microcontroller/UART_GPS_OUT: R3.1; also elsewhere on the board
/Microcontroller/UART_RN_IN: U5.7 (UART_RX); also elsewhere on the board
/Microcontroller/UART_RN_OUT: U5.6 (UART_TX); also elsewhere on the board
/Sheet5C378858/GPS_POWER: C1.3, C3.1, C13.1, C25.1, U2.1 (VCC_IO), U2.9 (VCC)
/Sheet5C378858/RN_PGC: J16.5, U5.30 (TEST0)
/Sheet5C378858/RN_PGD: J16.4, U5.31 (TEST1)
/Sheet5C378858/RN_POWER: C5.1, C12.1, C19.3, C23.1, C24.1, J16.2, R10.1, U5.12 (VDD), U5.34 (VDD)
GND: C1.2, C3.2, C5.2, C12.2, C13.2, C19.2, C23.2, C24.2, C25.2, J16.3, J17.2 (Ext), U2.4 (GND), U2.5 (GND), U2.10 (GND), U2.11 (GND), U2.12 (GND), U2.13 (GND), U2.14 (GND), U2.15 (GND), U2.18 (GND), U2.19 (GND), U2.21 (GND), U2.22 (GND), U2.27 (GND), U2.31 (GND), U5.1 (GND), U5.8 (GND), U5.11 (GND), U5.20 (GND), U5.21 (GND), U5.22 (GND), U5.24 (GND), U5.26 (GND), U5.27 (GND), U5.28 (GND), U5.33 (GND), U5.41 (GND), U5.47 (GND); also elsewhere on the board
unnamed: J17.1 (In), U5.23 (RFH)
unnamed: R2.1, U2.26 (RXD/SPI_MOSI)
unnamed: R3.2, U2.25 (TXD/SPI_MISO)
unnamed: U2.16 (RF_OUT), U2.17 (RF_IN)
V_3.3: C1.1, C19.1; also elsewhere on the board
V_BAK: U2.8 (V_BCKP); also elsewhere on the board

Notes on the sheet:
Global power labels
RN Module
GPS Module

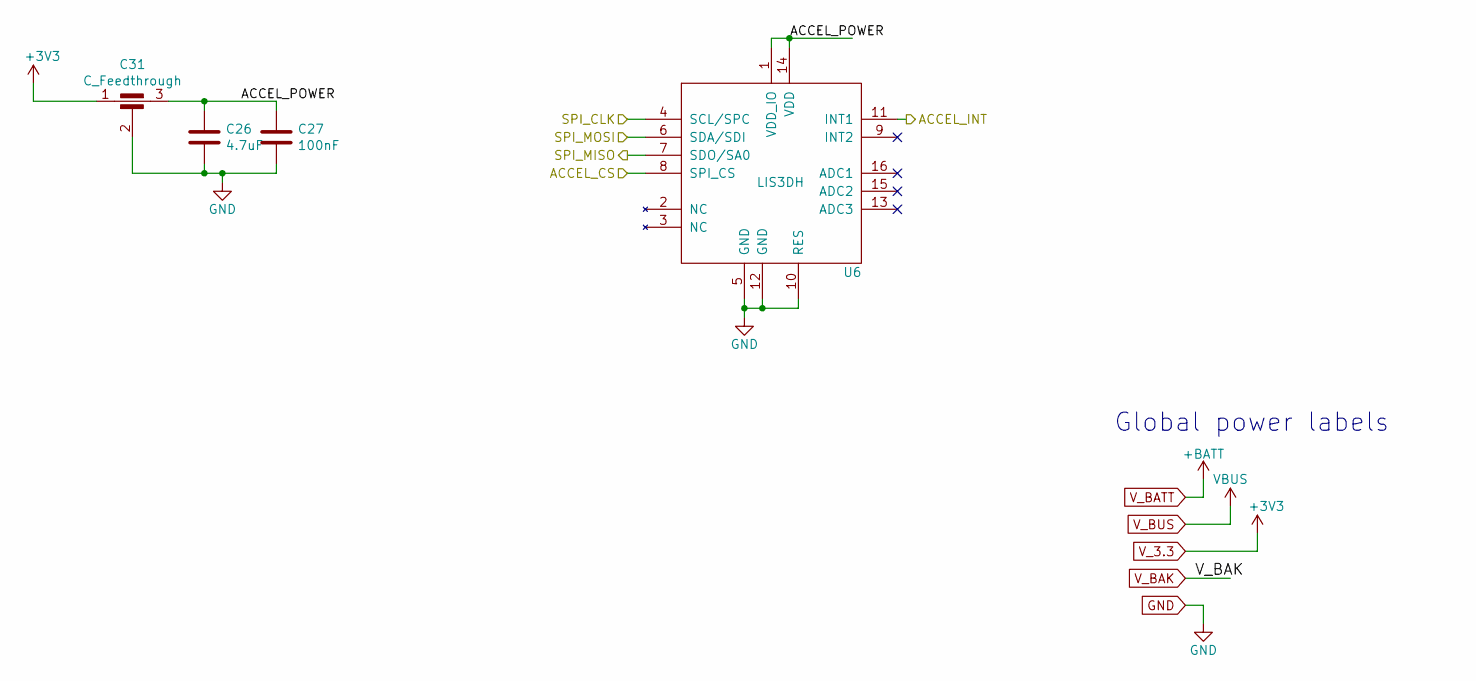
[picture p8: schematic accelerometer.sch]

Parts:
C26: 4.7uF; C_0805_2012Metric
C27: 100nF; C_0805_2012Metric
C31: C_Feedthrough; C_FEEDTHROUGH_0805
U6: LIS3DH; LGA-16_3x3mm_P0.5mm_LayoutBorder3x5y

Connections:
/Microcontroller/ACCEL_CS: U6.8 (SPI_CS); also elsewhere on the board
/Microcontroller/ACCEL_INT: U6.11 (INT1); also elsewhere on the board
/Microcontroller/SPI_CLK: U6.4 (SCL/SPC); also elsewhere on the board
/Microcontroller/SPI_MISO: U6.7 (SDO/SA0); also elsewhere on the board
/Microcontroller/SPI_MOSI: U6.6 (SDA/SDI); also elsewhere on the board
/accelerometer/ACCEL_POWER: C26.1, C27.1, C31.3, U6.1 (VDD_IO), U6.14 (VDD)
GND: C26.2, C27.2, C31.2, U6.5 (GND), U6.10 (RES), U6.12 (GND); also elsewhere on the board
V_3.3: C31.1; also elsewhere on the board

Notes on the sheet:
Global power labels

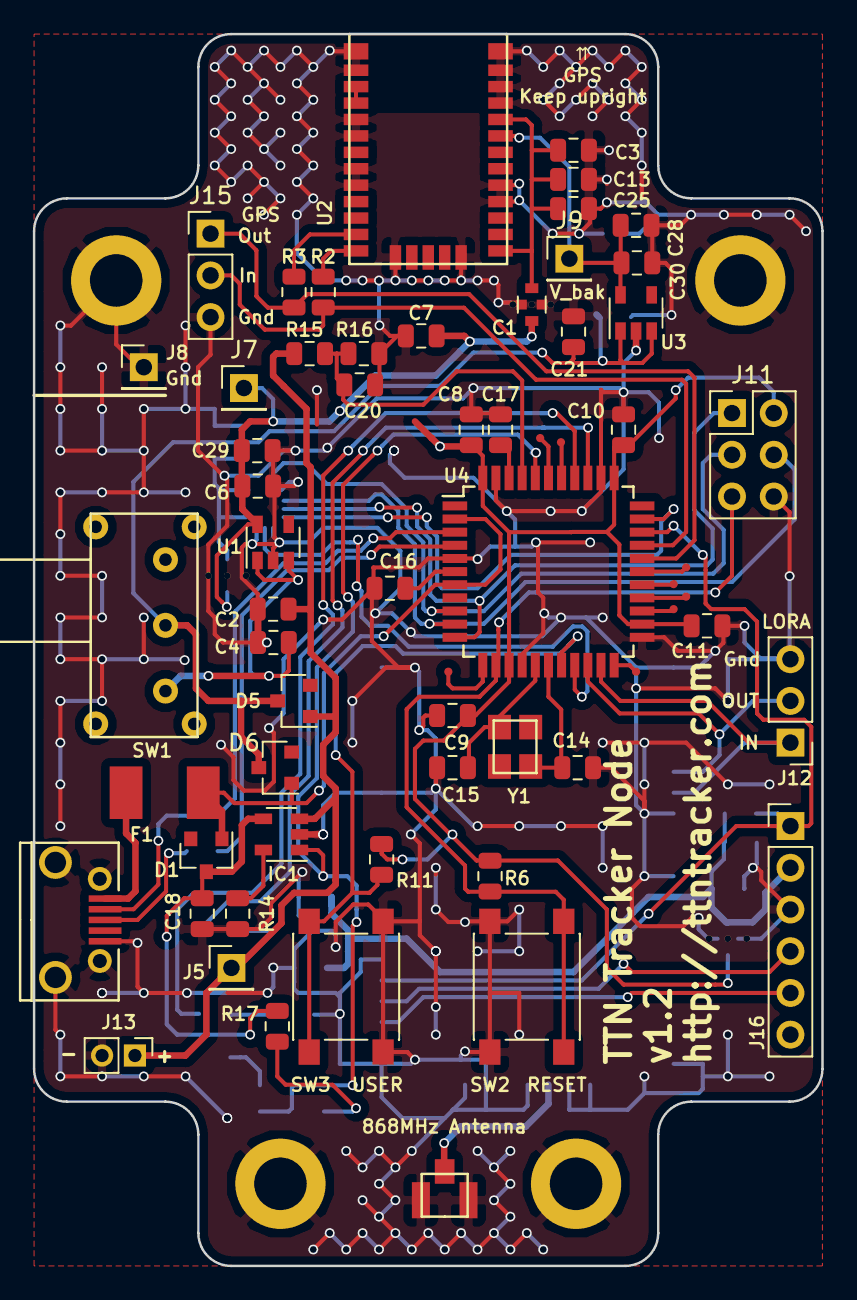
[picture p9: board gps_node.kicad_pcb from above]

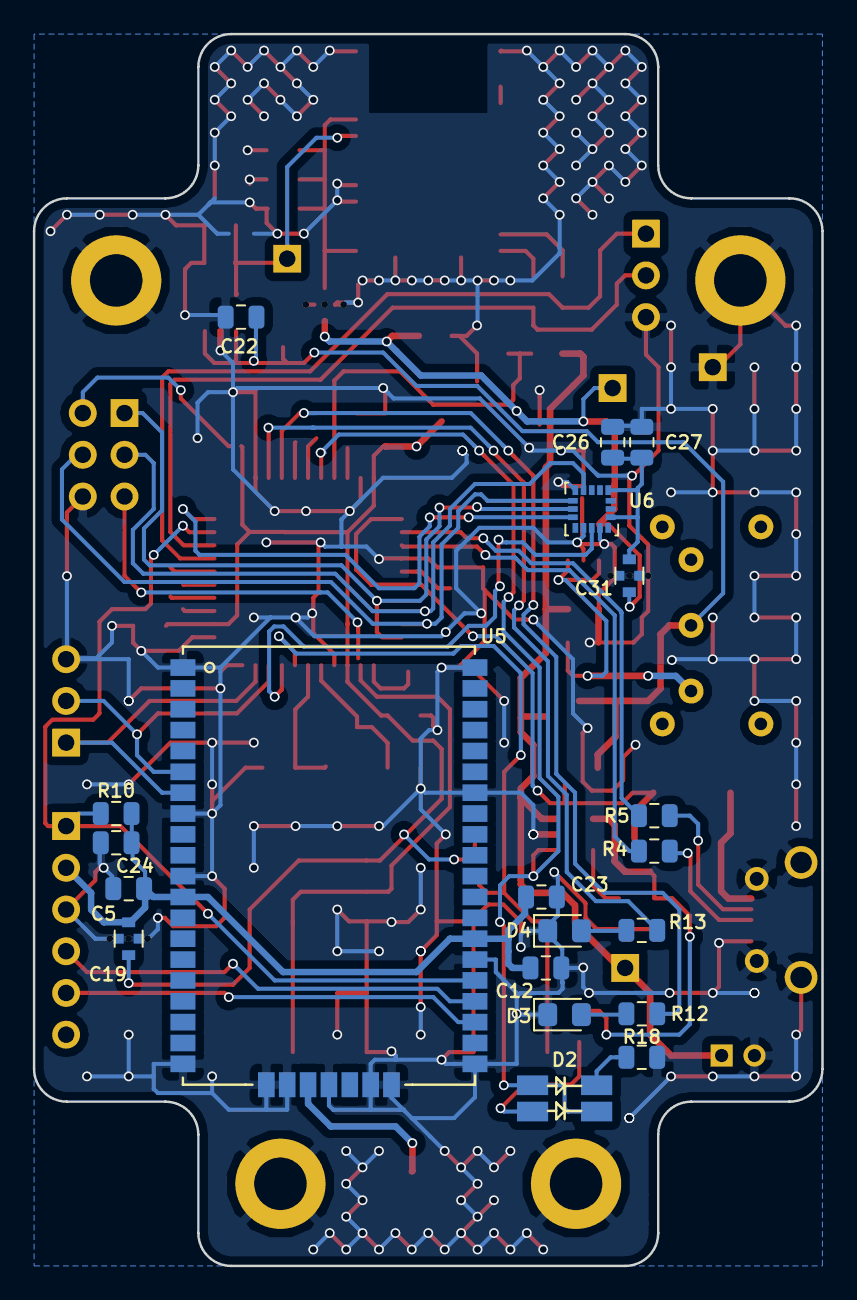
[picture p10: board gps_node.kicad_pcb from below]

Board: 2 copper layers, 48.0 x 75.0 mm, 86 parts (20 on the bottom side), 55 nets.

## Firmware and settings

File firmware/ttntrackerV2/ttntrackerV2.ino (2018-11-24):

/*
 * Author: JP Meijers
 * Date: 2016-09-07
 * 
 * RGB LED status:
 * Red   = Configuring radio and joining network
 * Purple = Waiting for an initial gps fix
 * Blue  = Wating for a fresh gps fix
 * Green    = busy transmitting and waitng for the RX windows
 *
 * Coordinates from the GPS is packed into a LoRaWan packet using binary
 * encoding, and then sent out on the air using the RN2xx3 module.
 * This happens as fast as possible, while still keeping to the 1% duty cycle
 * rules enforced by the RN2483's built in LoRaWAN stack. Even though this is
 * allowed by the radio regulations of the 868MHz band, the fair use policy of
 * TTN may prohibit this. CHECK THE RULES BEFORE USING THIS PROGRAM!
 *
 * CHANGE ADDRESS!
 * Change the device address, network (session) key, and app (session) key to
 * the values that are registered via the TTN dashboard.
 * The appropriate line is "myLora.initABP(XXX);" or "myLora.initOTAA(XXX);"
 * When using ABP, it is advised to enable "relax frame count" on the dashboard.
 * When using OTAA, register the boards Device EUI as is printed out over Serial at startup.
 *
 * TO CONTRIBUTE TO TTN Mapper:
 * 1. Register a new Application and/or new device on the
 *     TTN Dashboard (https://console.thethingsnetwork.org).
 * 2. Copy the correct keys into the line "myLora.initABP(XXX);"
 *     or "myLora.initOTAA(XXX);" in this program.
 * 3. Make sure packets are arriving on the TTN console when your node is
 *     powered and in reach of a gateway.
 * 4. Add the payload decoder as shown below and make sure the payloads are decoded correctly.
 * 5. Enable the TTN Mapper integration.
 *

function Decoder(bytes, port) {
  // Decode an uplink message from a buffer
  // (array) of bytes to an object of fields.
  var decoded = {};

  // if (port === 1) decoded.led = bytes[0];
  decoded.lat = ((bytes[0]<<16)>>>0) + ((bytes[1]<<8)>>>0) + bytes[2];
  decoded.lat = (decoded.lat / 16777215.0 * 180) - 90;

  decoded.lon = ((bytes[3]<<16)>>>0) + ((bytes[4]<<8)>>>0) + bytes[5];
  decoded.lon = (decoded.lon / 16777215.0 * 360) - 180;

  var altValue = ((bytes[6]<<8)>>>0) + bytes[7];
  var sign = bytes[6] & (1 << 7);
  if(sign)
  {
    decoded.alt = 0xFFFF0000 | altValue;
  }
  else
  {
    decoded.alt = altValue;
  }

  decoded.hdop = bytes[8] / 10.0;

  return decoded;
}

 *
 */
#include "TinyGPS++.h"
#include <SoftwareSerial.h>
#include <rn2xx3.h>


#define RN_RESET 5
#define GPS_RX 9
#define GPS_TX 10

#define LED_RED A1
#define LED_YEL A0


#define PMTK_SET_NMEA_UPDATE_05HZ  "$PMTK220,2000*1C"
#define PMTK_SET_NMEA_UPDATE_1HZ  "$PMTK220,1000*1F"
#define PMTK_SET_NMEA_OUTPUT_RMCGGA "$PMTK314,0,1,0,1,0,0,0,0,0,0,0,0,0,0,0,0,0,0,0*28"


SoftwareSerial gpsSerial(GPS_RX, GPS_TX); // RX, TX
TinyGPSPlus gps;
rn2xx3 myLora(Serial1);

unsigned long last_update = 0;
String toLog;
uint8_t txBuffer[11];
uint32_t LatitudeBinary, LongitudeBinary;
uint16_t altitudeGps;
uint8_t hdopGps;


void setup() {

  pinMode(LED_RED, OUTPUT);
  pinMode(LED_YEL, OUTPUT);

  digitalWrite(LED_RED, HIGH);
  digitalWrite(LED_YEL, HIGH);
  
  // RN2483 reset
  pinMode(RN_RESET, OUTPUT);
  digitalWrite(RN_RESET, LOW);
  delay(100);
  digitalWrite(RN_RESET, HIGH);
  delay(100);

  Serial.begin(57600); //serial to computer
  //gpsSerial.begin(9600); //serial to gps
  Serial1.begin(57600); //serial to RN2xx3

  // make sure usb serial connection is available,
  // or after 10s go on anyway for 'headless' use of the
  // node.
  while ((!Serial) && (millis() < 10000));

  Serial.println("TTN Tracker");

  //set up RN2xx3
  initialize_radio();
  //transmit a startup message
  myLora.tx("TTN Tracker");
  digitalWrite(LED_RED, LOW);
  digitalWrite(LED_YEL, LOW);

  // Only start receivng GPS data after we chatted to the RN2483
  gpsSerial.begin(9600);
  
  delay(1000);
}

void initialize_radio()
{
  //print out the HWEUI so that we can register it via ttnctl
  myLora.autobaud();
  String hweui = myLora.hweui();
  while(hweui.length() != 16)
  {
    Serial.println("Communication with RN2xx3 unsuccessful. Power cycle the board.");
    Serial.println(hweui);
    digitalWrite(RN_RESET, LOW);
    delay(1000);
    digitalWrite(RN_RESET, HIGH);
    delay(1000);
    hweui = myLora.hweui();
  }
  Serial.println("When using OTAA, register this DevEUI: ");
  Serial.println(hweui);
  Serial.println("RN2xx3 firmware version:");
  Serial.println(myLora.sysver());

  Serial.println("Setting frequency plan");
  myLora.setFrequencyPlan(TTN_EU);

  //configure your keys and join the network
  Serial.println("Trying to join TTN");
  bool join_result = false;

  //myLora.setDR(5);
  //ABP: initABP(String addr, String AppSKey, String NwkSKey);
  join_result = myLora.initABP("2601191A", "698C7778BD638C74BE27C74A304A23A4", "6829BDBCD81E9570EFC8A64DEF6C923A");

  //OTAA: initOTAA(String AppEUI, String AppKey);
//  join_result = myLora.initOTAA("70B3D57EF0001D09", "AF1A989DFB6A80E42D05009A7861C699");

  while(!join_result)
  {
    Serial.println("Unable to join. Are your keys correct, and do you have TTN coverage?");
    delay(20000); //delay a minute before retry
    join_result = myLora.init();
  }
  Serial.println("Successfully joined TTN");

  myLora.setDR(5);
  myLora.sendRawCommand(F("mac set adr off"));
}

void loop() {
  while (gpsSerial.available()){
    digitalWrite(LED_RED, HIGH);
    char c = gpsSerial.read();
    gps.encode(c);
    //Serial.write(c);
    digitalWrite(LED_RED, LOW);
  }

  if (gps.location.age() < 1000 && (millis() - last_update) >= 1000) {
    gpsSerial.end();
    
    Serial.print("Interval: ");
    Serial.println(millis()-last_update);

    build_packet();

    Serial.println(toLog);
    digitalWrite(LED_YEL, HIGH);
    myLora.txBytes(txBuffer, sizeof(txBuffer));
    digitalWrite(LED_YEL, LOW);
    Serial.println("TX done");

    last_update = millis();
    gpsSerial.begin(9600);
  }
}

void build_packet()
{
  LatitudeBinary = ((gps.location.lat() + 90) / 180.0) * 16777215;
  LongitudeBinary = ((gps.location.lng() + 180) / 360.0) * 16777215;

  txBuffer[0] = ( LatitudeBinary >> 16 ) & 0xFF;
  txBuffer[1] = ( LatitudeBinary >> 8 ) & 0xFF;
  txBuffer[2] = LatitudeBinary & 0xFF;

  txBuffer[3] = ( LongitudeBinary >> 16 ) & 0xFF;
  txBuffer[4] = ( LongitudeBinary >> 8 ) & 0xFF;
  txBuffer[5] = LongitudeBinary & 0xFF;

  altitudeGps = gps.altitude.meters();
  txBuffer[6] = ( altitudeGps >> 8 ) & 0xFF;
  txBuffer[7] = altitudeGps & 0xFF;

  hdopGps = gps.hdop.value()/10;
  txBuffer[8] = hdopGps & 0xFF;

  //course and speed
  txBuffer[9] = (int(gps.course.deg()) / 10) & 0xFF;
  txBuffer[10] = int(gps.speed.kmph()) & 0xFF;

  toLog = "";
  for(size_t i = 0; i<sizeof(txBuffer); i++)
  {
    char buffer[3];
    sprintf(buffer, "%02x", txBuffer[i]);
    toLog = toLog + String(buffer);
  }
}

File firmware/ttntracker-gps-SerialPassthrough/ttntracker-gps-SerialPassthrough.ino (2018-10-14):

/*
  SerialPassthrough sketch

  Some boards, like the Arduino 101, the MKR1000, Zero, or the Micro, have one
  hardware serial port attached to Digital pins 0-1, and a separate USB serial
  port attached to the IDE Serial Monitor. This means that the "serial
  passthrough" which is possible with the Arduino UNO (commonly used to interact
  with devices/shields that require configuration via serial AT commands) will
  not work by default.

  This sketch allows you to emulate the serial passthrough behaviour. Any text
  you type in the IDE Serial monitor will be written out to the serial port on
  Digital pins 0 and 1, and vice-versa.

  On the 101, MKR1000, Zero, and Micro, "Serial" refers to the USB Serial port
  attached to the Serial Monitor, and "Serial1" refers to the hardware serial
  port attached to pins 0 and 1. This sketch will emulate Serial passthrough
  using those two Serial ports on the boards mentioned above, but you can change
  these names to connect any two serial ports on a board that has multiple ports.

  created 23 May 2016
  by Erik Nyquist
*/
#include <SoftwareSerial.h>
SoftwareSerial gpsSerial(9, 10);

void setup() {
  Serial.begin(9600);
  gpsSerial.begin(9600);
}

void loop() {
  if (Serial.available()) {      // If anything comes in Serial (USB),
    gpsSerial.write(Serial.read());   // read it and send it out Serial1 (pins 0 & 1)
  }

  if (gpsSerial.available()) {     // If anything comes in Serial1 (pins 0 & 1)
    Serial.write(gpsSerial.read());   // read it and send it out Serial (USB)
  }
}

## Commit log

2017-12-09 Add gps module
    [gps_node.sch]
2017-12-09 Add accelerometer
    [gps_node.sch]
2017-12-09 Add connector for battery and solar panel
    [gps_node.sch]
2017-12-09 Connect accelerometer interrupts
    [gps_node.sch]
2017-12-09 Add ICSP header
    [gps_node.sch]
2017-12-10 Cleaned up schematic, change avrisp component
    [gps_node.sch]
2017-12-10 Add status LEDs for charger
    [gps_node.sch]
2017-12-10 Moves schematic to own folder
    [gps_node.kicad_pcb, gps_node.sch]
2017-12-11 Changed battery measurement
    [gps_node.sch]
2018-01-12 Updates to power segment
    [gps_node.sch]
2018-01-13 Add test and debug points
    [gps_node.sch]
2018-01-13 Fix capacitor
    [gps_node.sch]
2018-01-13 Schematic updated
    [gps_node.sch, gps_node_bom.csv]
2018-01-23 Footprints almost done, starting pcb layout
    [gps_node.kicad_pcb, gps_node.sch, gps_node_bom.csv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]
2018-02-04 First round of layout done
    [gps_node.kicad_pcb, gps_node.sch]
2018-02-05 Issue #2: Adds RN2483 reset pin
    [gps_node.kicad_pcb, gps_node.sch]
2018-03-25 Adds RGB led, updates schematic
    [gps_node.kicad_pcb, gps_node.sch]
2018-03-28 Added more group pour aroudd gps, additional buttons
    [gps_node.kicad_pcb, gps_node.sch]
2018-10-14 Move v1 schematic to subfolder
    [gps_node.kicad_pcb, gps_node.sch, gps_node_v0.0.1_bom.csv]
2018-10-14 Add v2 schematic
    [gps_node-B.Cu.gbr, gps_node-B.Mask.gbr, gps_node-B.SilkS.gbr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]
2018-11-07 Add design files for enclosure
2018-11-07 Adds schematic version 3
    [gps_node-2018-11-07-07-07-34.sch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]
2018-11-07 Updated d3 schematic to multiple sheets
    [GPS_and_Radio.sch, Microcontroller.sch, gps_node.sch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]
2018-11-07 Small cleanup
    [GPS_and_Radio.sch, Microcontroller.sch, gps_node.sch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]
2018-11-08 Started PCB layout
    [GPS_and_Radio.sch, Microcontroller.sch, gps_node.kicad_pcb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]
2018-11-08 Started layout work
    [GPS_and_Radio.sch, Microcontroller.sch, gps_node.kicad_pcb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]
2018-11-09 More layout work
    [gps_node.kicad_pcb, power.sch]
2018-11-09 More layout
    [gps_node.kicad_pcb]
2018-11-10 Adds Accelerometer, layout almost done
    [GPS_and_Radio.sch, Microcontroller.sch, accelerometer.sch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]
2018-11-11 Fixed battery connector, started bom
    [Microcontroller.sch, accelerometer.sch, gps_node.csv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]
2018-11-11 Update BOM, so old components
    [Microcontroller.sch, gps_node.csv, power.sch]
2018-11-12 Moved usb connector
    [gps_node.kicad_pcb]
2018-11-15 Removed 4th led from sticker
2018-11-24 Add pdf of enclosure sketch
2018-11-24 Add diodes before on/off switch to power device from either USB or battery
    [power.sch]
2018-11-24 Add 4.7uF caps around battery charger
    [power.sch]
2018-11-24 Add feedthrough cap for accelerometer
    [accelerometer.sch]
2018-11-24 Change accelerometer power label
    [accelerometer.sch]
2018-11-24 Replace 10uF by 4.7uF and clean up power circuit
    [GPS_and_Radio.sch, Microcontroller.sch, accelerometer.sch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]
2018-11-24 Cleaned up schematic
    [GPS_and_Radio.sch, Microcontroller.sch, accelerometer.sch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]
2018-11-26 Updated layout to revised schematic, moved switch and usb
    [gps_node.kicad_pcb, power.sch]
2018-11-26 Updated layout
    [gps_node.kicad_pcb, gps_node_v0.0.1_bom.csv]
2018-11-26 Update layout, updated drawings
    [gps_node.kicad_pcb]
2018-11-27 Updated BOM
    [gps_node_bom.csv, gps_node_bom_temp.csv]
2021-11-08 Update README.md
    https://forum.kicad.info/t/warning-avoid-all-links-to-kicad-pcb-org-use-kicad-org/31521
